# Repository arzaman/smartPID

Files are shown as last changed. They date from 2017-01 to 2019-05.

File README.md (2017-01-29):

# smartPID

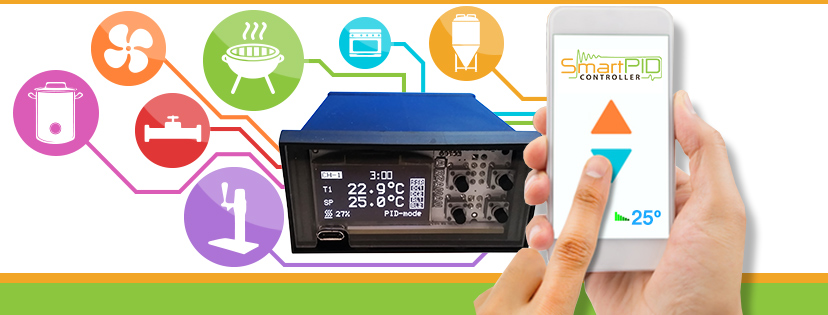
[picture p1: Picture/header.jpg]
smartpid header

Professionally engineered, SmartPID Controller is a high-tech product that facilitates temperature and process control: heating or cooling. 
Compared to your basic on/off thermostat, SmartPID is a piece of futuristic wonder.  

Compared to simple on/off thermostat SmartPID controller can collect temperature from multiple sensors, apply a custom and programmable control logic and drive different load (heater, cooler, valve, fan) with PID precision algorithm
You can easily replace your thermostat and add full process control to your application, data log and remote management

SmartPID Controller can control any thermo regulated process (heating or cooling) and any applications locally or remotely
It is flexible and very powerful device which can be programmed and adapted to any custom application

SmartPID Controller is 100 compatible with Arduino ecosystem

SmartPID Controller is a must device for Do-It- Yourself Enthusiasts, Software geeks, Makers, but also professionals that need affordable process controller

From homebrewing or wine making to aquarium or refolow oven temperature control SmartPID can add precision, power, flexibility programmability

In one word make your temperature process control SMART

All applications benefit from a full set of common features that are the baseline to developing smart applications.

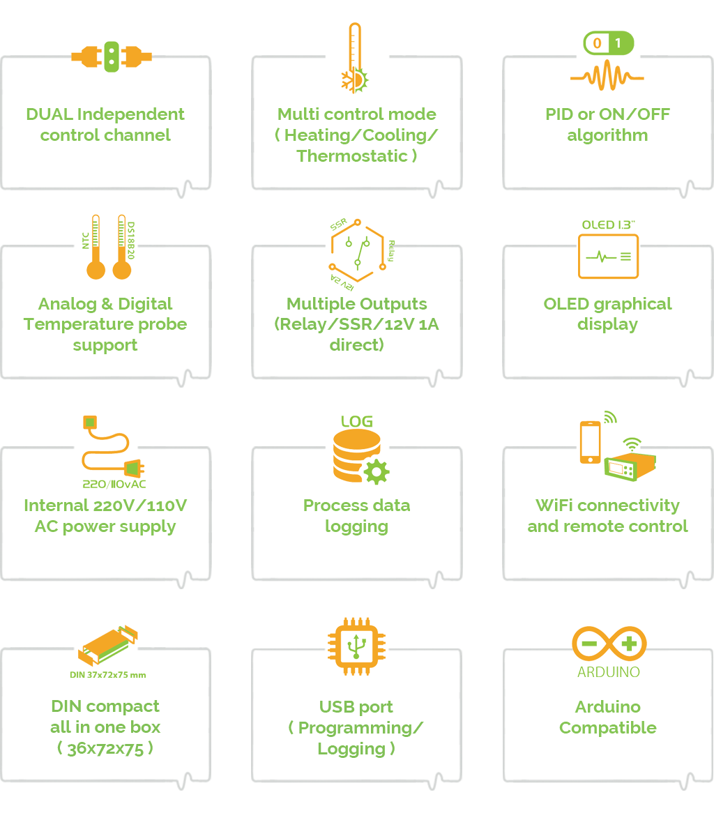
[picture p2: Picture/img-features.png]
smartpid feature


SmartPID is a masterpiece of engineering. We have done our best to incorporate a ton of advanced features into a single compact box. Below you will find a table with all technical characteristic

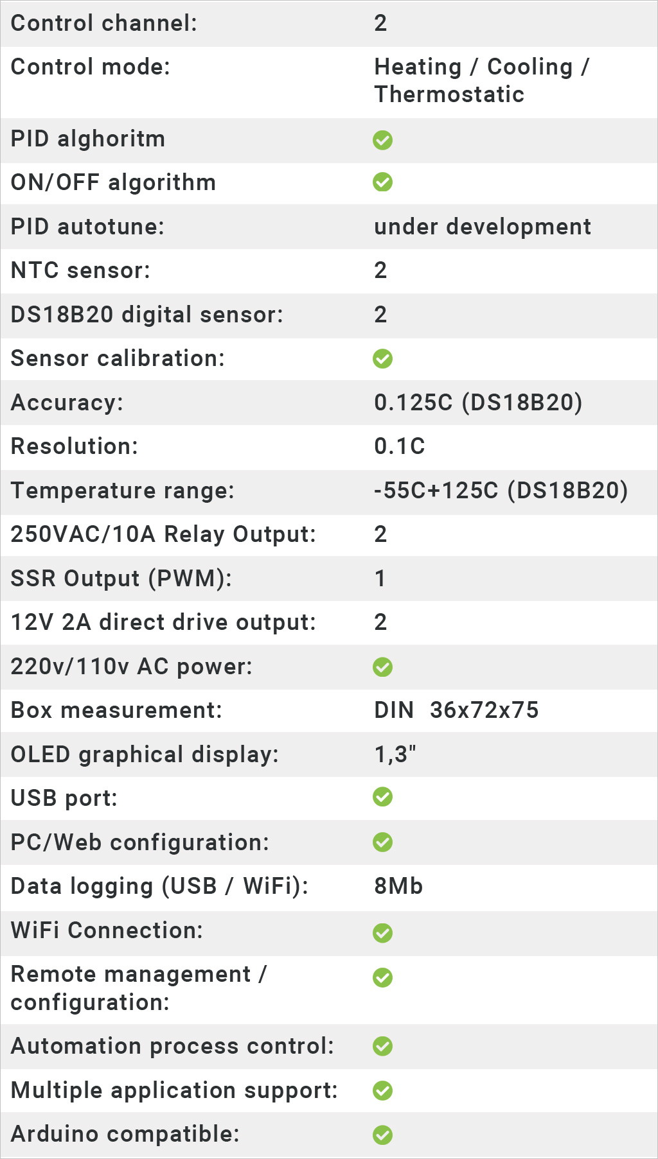
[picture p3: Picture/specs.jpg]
smartpid technical


SmartPID is powered by SAMD21 32-bit ARM® Cortex®-M0+ by Atmel

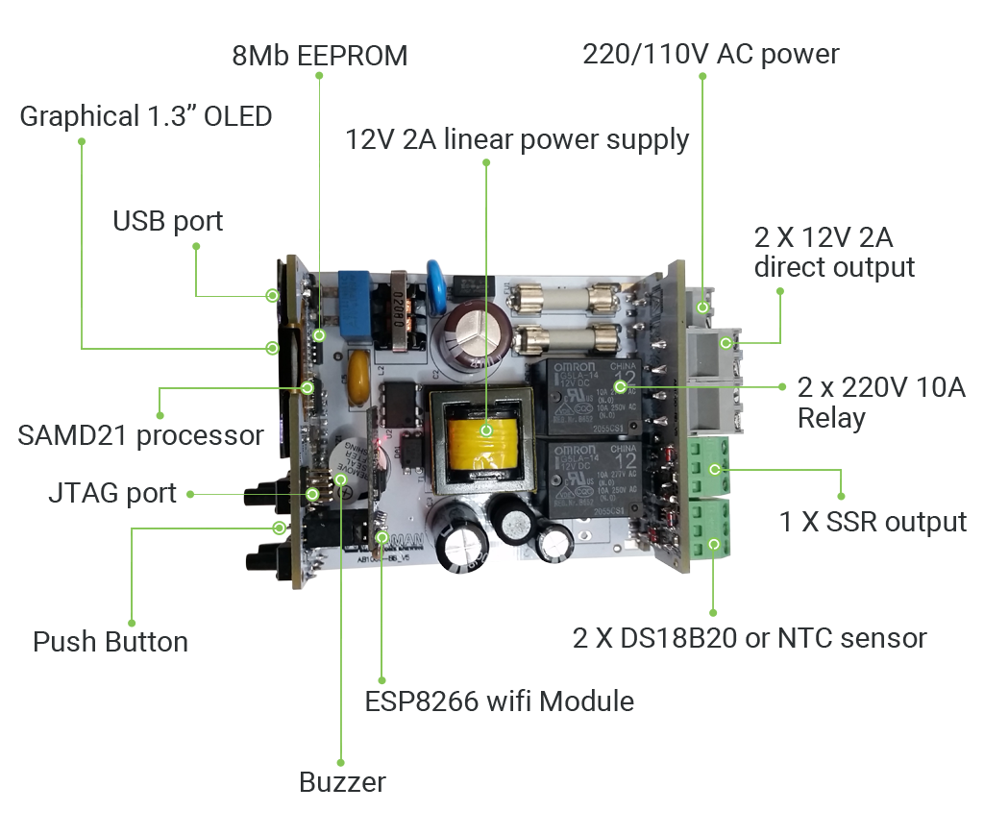
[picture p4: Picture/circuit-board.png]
smartpid circuit board


 SmartPID is 100% compatible with the Arduino echo system: you can plug in your PC via USB and program through the Arduino IDE.   

The key benefits of this design choice are

SAMD21 processor-based (like Zero or MKR1000)   
Dedicated USB bootloader and board definition   
Fully programmable via Arduino IDE   
Full set of support libraries available
smartPID has been designed by a maker for the maker community

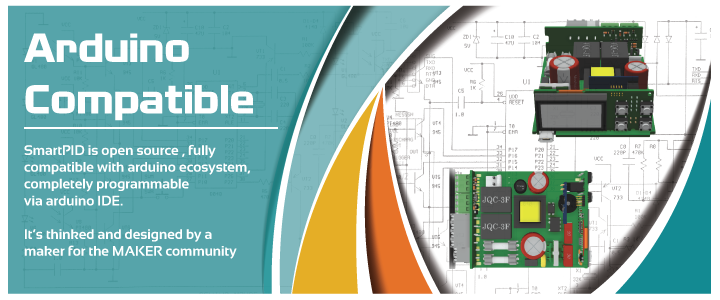
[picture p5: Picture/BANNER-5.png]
smartpid arduino


smartPID IS IoT ready 

One of the unique smart features of the SmartPID Controller is its capability to store process log data and then make that data available either locally via USB interface or remotely via the cloud. 

You can easily access your data from the web on a desktop, smartphone, or tablet, which is perfect in case of critical situations that involve alarms and triggers. 

Plus, if your fridge goes into a block stage or your food dehydrator finishes its process, you can set up SmartPID to let you know.

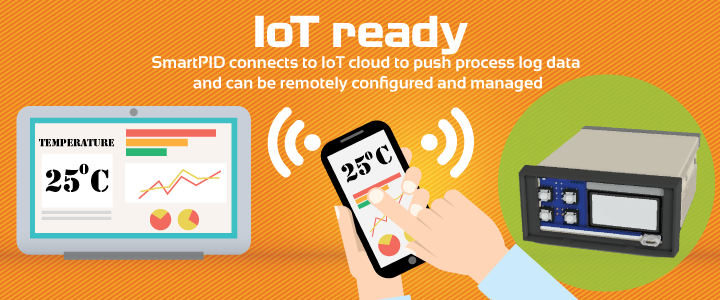
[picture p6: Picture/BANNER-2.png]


SmartPID is connected to thingspeak

Among many different possible IoT solutions for SmartPID in this phase is the Thingspeak service. 

Thingspeak is based on a number of useful features that make it easy to use and integrate the SmartPID project.

-Real-time data collection and storage of process data generated by SmartPID

-Simple and effective data visualization in both private and public channels

-MATLAB® for data analysis and manipulation

-Alerts and triggers for integration with other services

-Scheduling

-Open API

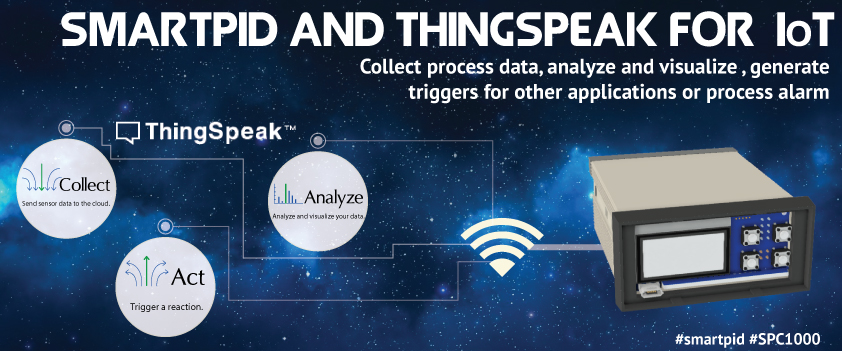
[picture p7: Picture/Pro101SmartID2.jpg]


The relevant code is available on github, and in the future, a dedicated cloud service will be provided

SmartPID dedicated APP

We have developed a mobile app prototype for Android in order to retrieve data from the cloud server and in turn visualize that data on a smartphone.  

SmartPID pushes log data to a remote server so that the mobile app can retrieve it in a secure and encrypted way.

The smart app allows you to do the following:  

-Login and authenticate user login on the server in order to access it in a secure way  

-Display and visualize data via a dashboard so that the user can select a specific controller and data (filtered by date/time) and display the data in a graphic or tabular way 
 
-Configure the device (this part is still under development)

-You can configure all the unit parameters (HW set up, process parameter) via a web interface or mobile app and upload your configuration options on the device. Configuration options can then be stored on the server and used at any time. 

You can also set a temperature threshold and get notifications by local alarm, email, or Twitter.

developing application for both android and IOS and set up all the server infrastructure is complex and requires lot of investment, this is one of the part in scope od the crowdfunding campaing

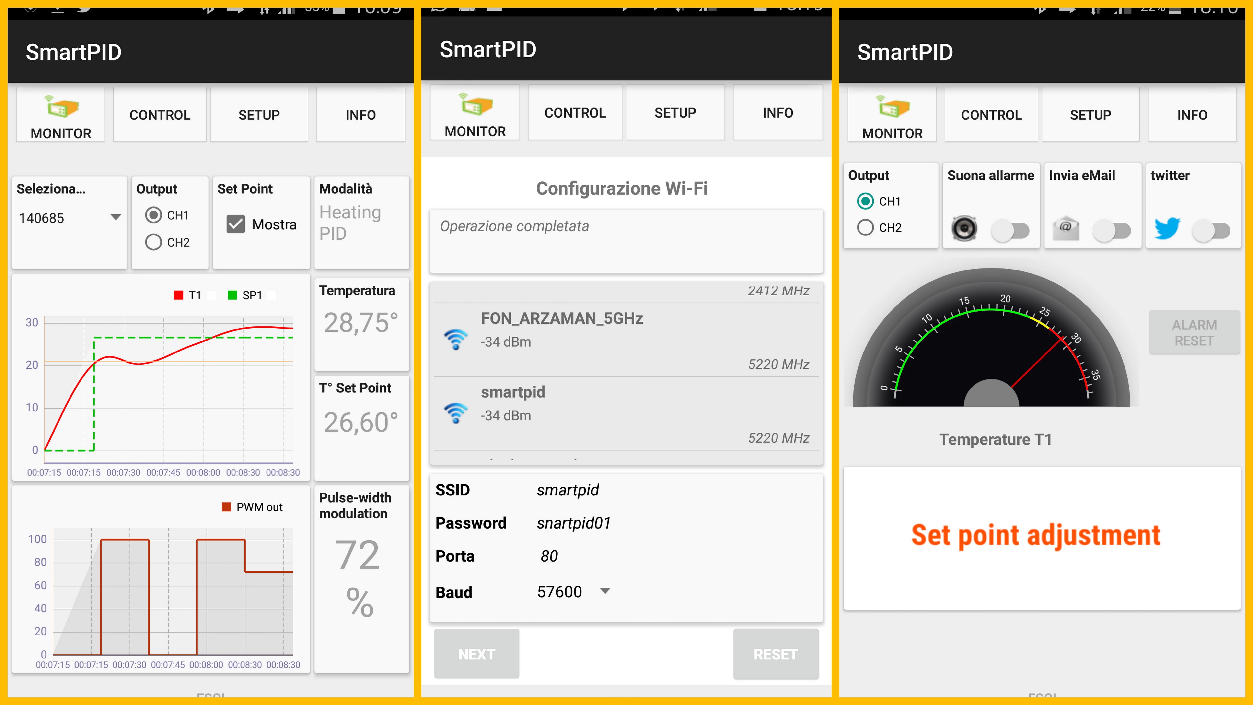
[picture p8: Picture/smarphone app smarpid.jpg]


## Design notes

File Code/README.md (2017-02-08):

# TEST APP code

this folder contains the source code for a test application that allow you to perform test of all HW components

the code is complied with arduino IDE 1.6.13 and SAMD core 32 BIT ARM Cortex M0+ version 1.6.11
notice that the binary code produced should be loaded with the smartPID MSD bootloader and is not compatible witn SAM-BA bootloader

it's needed to instal smarPID board definitio, please see "driver" section

Test area:

MCU test 

EEPROM (read e write)

OLED (graphic and text)

tactile switch

buzzer

wifi module (serial connection and FW version)

temperature read (NTC and DS18B20 on both port)

oututput activation (SSR/relay/12V DC)

USB port test

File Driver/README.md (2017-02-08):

# DRIVER

this folder contains 

Board Definition. the information package to install the board under the arduino IDE

open your Arduino preferences (File > Preferences). Then find the Additional Board Manager URLs text box, and paste the below link 

https://raw.githubusercontent.com/arzaman/smartPID/master/Driver/SPC1000/package_arzaman_index.json

Then hit “OK”, and travel back to the Board Manager menu. You should (but probably won’t) be able to find a new entry for SPC1000 board. If you don’t see it, close the board manager and open it again.

USB serial driver

After downloading, copy down the location of the arzaman.inf file

Open your Device Manager
In Windows 8 or 10, simply search for "Device Manager" and select the Windows app
In the Device Manager, expand the "Other devices" tree -- you should see an entry for "Unknown Device", Right-click and select Update Driver Software...

Select Browse my computer for driver software. On the next screen

Paste the directory location of your arzaman.inf files into the search location. Then hit "Next".

Click "Install" when the next pop-up questions if you want to install the driver. If you get any warning for unknown source of the driver please accept.

The driver installation may take a moment, when it's done you should be greeted with a "successfully updated your driver software" message!

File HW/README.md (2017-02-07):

# HW (schematic and pcb)

this folder contains the SmartPID electric schema and PCB

the controller is composed by 3 PCBs

Front Board
contains the SAMD21 processor, the EEPROM, the OLED display and push button. there are 2 sockets one for the ESP8266 module and the other one for SWD programming.

Base Board
it connects the 3 PCBs and contains all the linear switching 220AC/12VDC power supply. On the board there are also the 2 mechanical relays and the buzzer

Rear Board
provides the I/O lines via terminal blocks and contains all the power driver and protection electronic

CAD file are in altium designer format

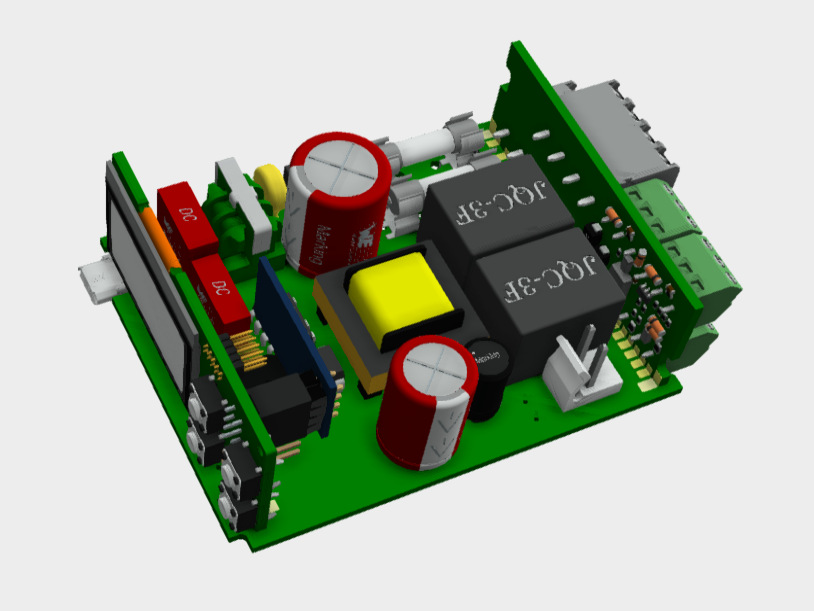
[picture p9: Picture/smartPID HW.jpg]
smartpid HW


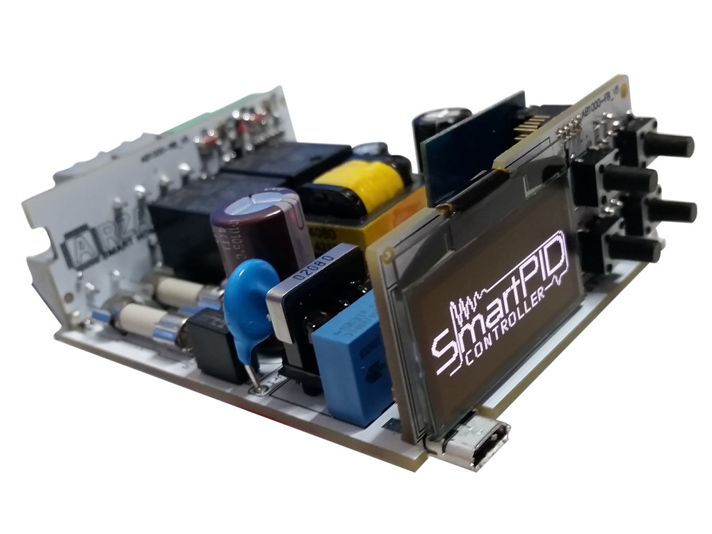
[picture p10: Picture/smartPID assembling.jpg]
smartpid assembling


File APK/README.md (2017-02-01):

# APK

this folder contains the the android application pakage 

download on your smartphone and please make sure that
Your android version is 5 or greater
You activate USB debug mode under development option menu
You accept during the installation APK from “unknown source”

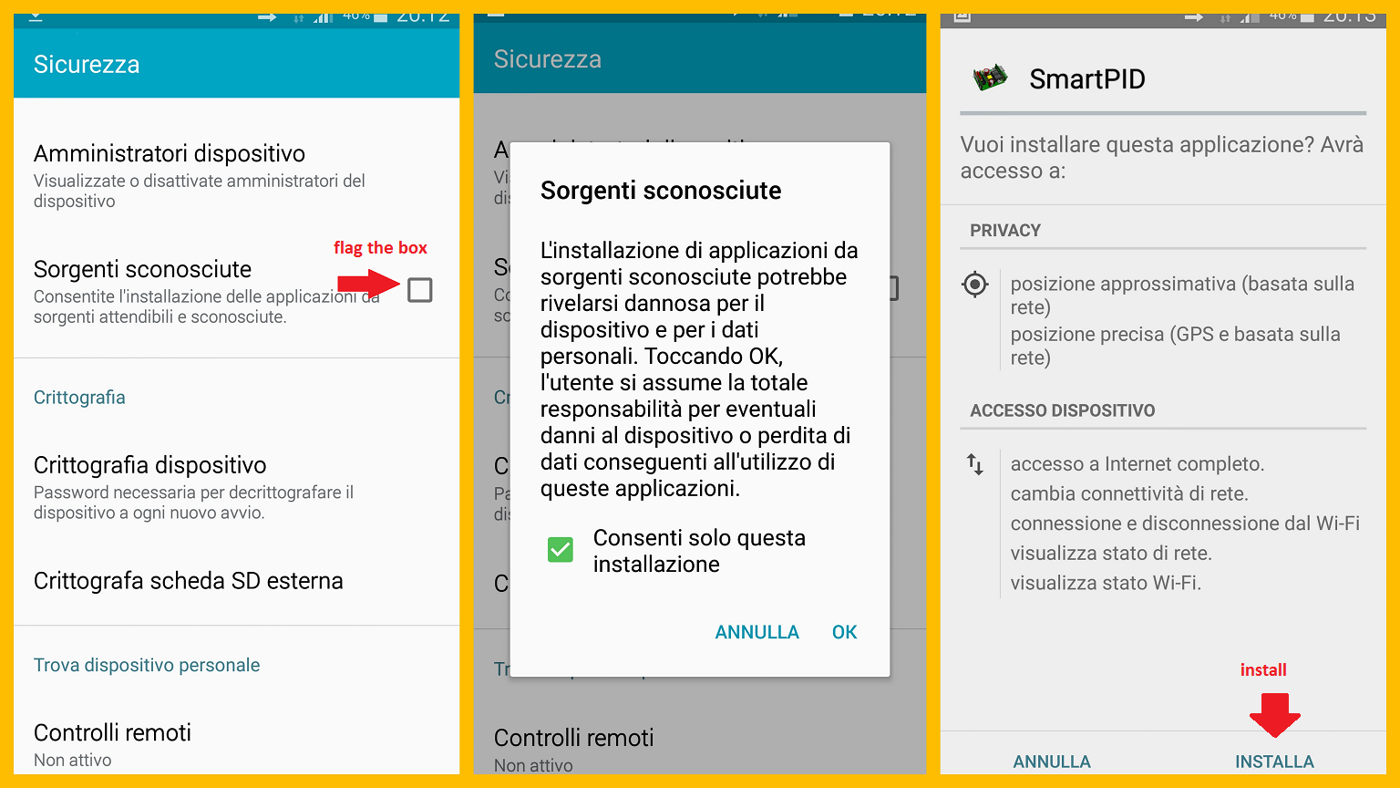
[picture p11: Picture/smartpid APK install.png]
APK install


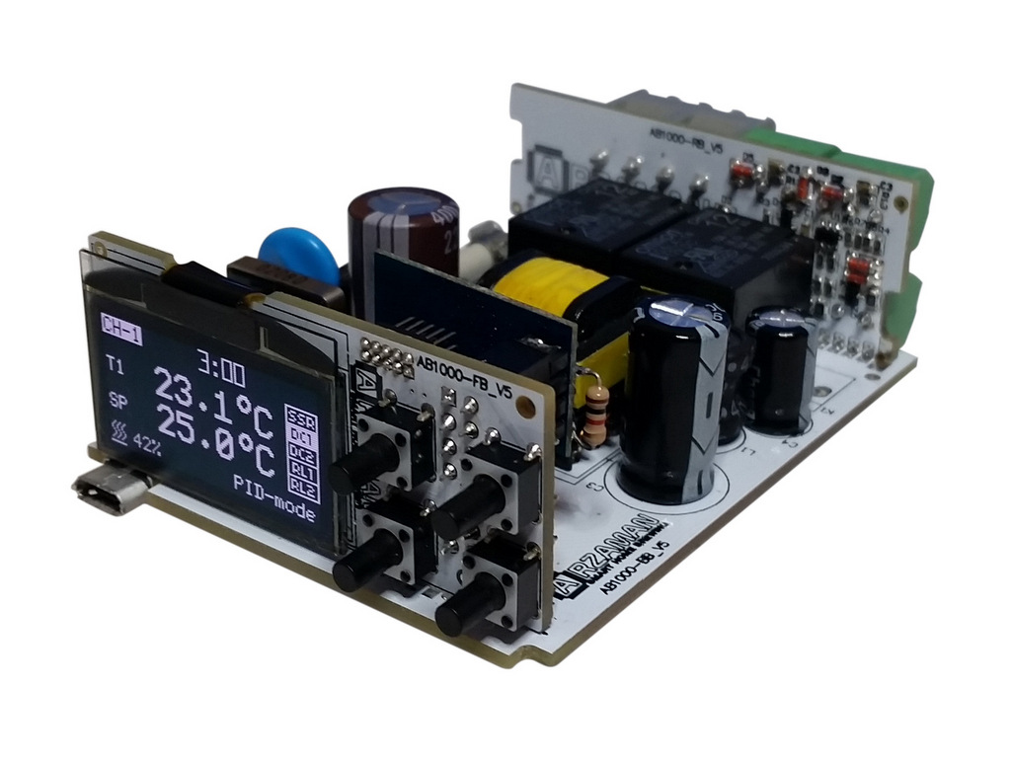
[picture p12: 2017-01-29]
Picture/smartPID HW overview (1).jpg

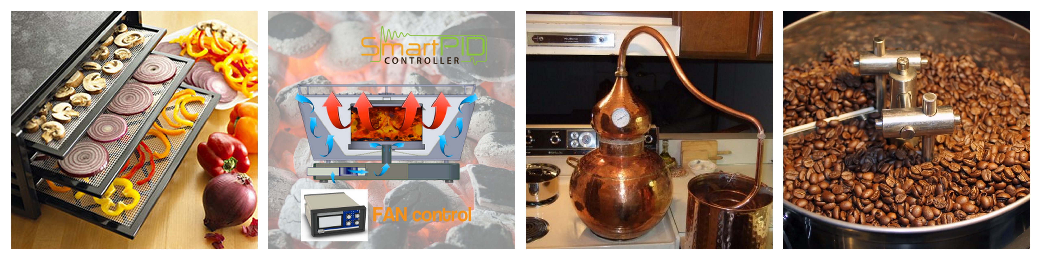
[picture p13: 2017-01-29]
Picture/multipe smartpid applications.jpg

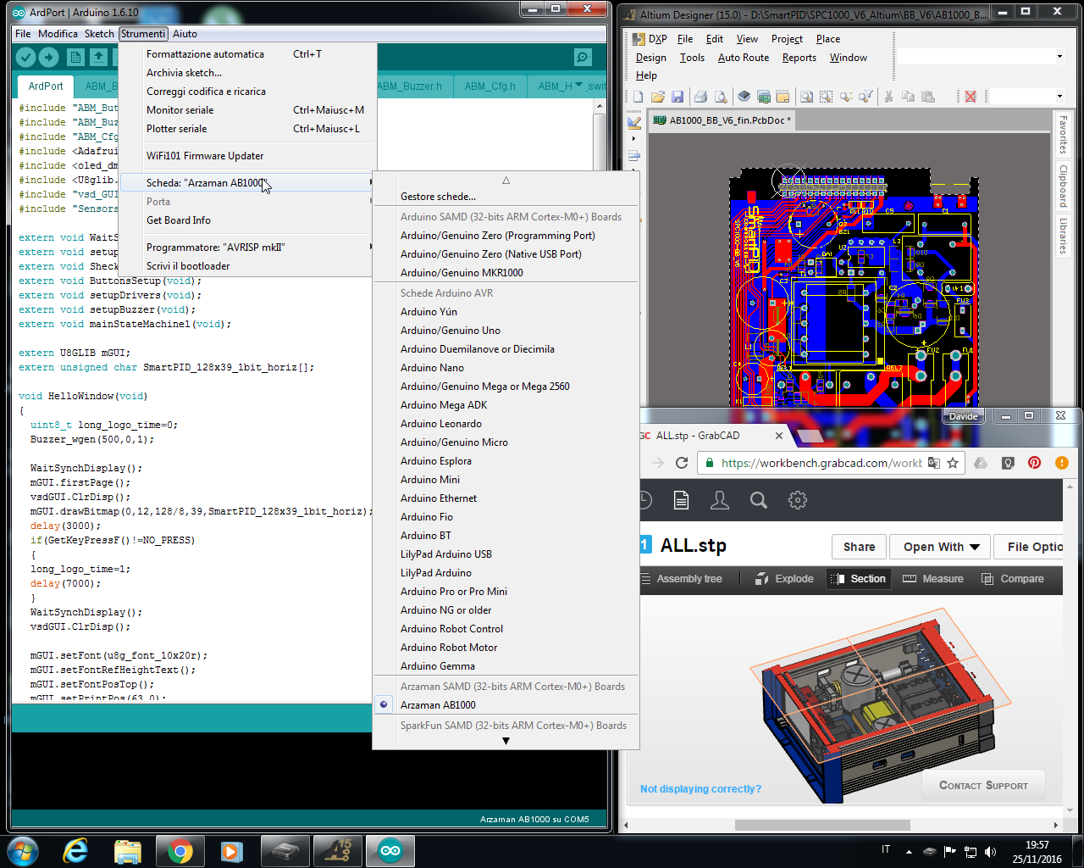
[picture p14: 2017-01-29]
Picture/2016-11-25 19_57_43-Greenshot (1).png

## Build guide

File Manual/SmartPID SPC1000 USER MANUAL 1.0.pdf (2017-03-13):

User Manual

# User manual

11-03-2017

Version 1.0

Company Information

Copyright and third-party information as required

## Document Revisions

Date

Version
Number

Document Changes

11/03/2017 | 1.0 | First draft

## Table of Contents

## Safety & Precaution

Ensure that the product is always used within the specifications

Do not use product close to flammable and explosive gas otherwise injury from explosion may occur

Never disassemble, modify, or touch any of the internal part to avoid electric shock or malfunctions

Do not use the relay over their life cycle and do not exceed the rated load of the outputs

Do not touch the terminals at least while power is being supplied. Doing so may occasionally result in injury due to electric shock.

enter the product.

Do not allow water or any liquid enter the product. Enclosure is not water prof

The board is sold as a DIY standalone component and people buying should take care of connecting and integrating with their own system. The manula connection diagram and short explanations but minimum expertise in electric circuit is needed.

The board is powered by High Voltage 220/110V so you must be very careful and all connections are at your own risk. If you are not familiar with electricity and power please ask a technician to help you. I'm not responsible for any damage or risk you can create

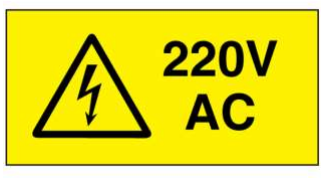
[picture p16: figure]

## 1 SmartPID SPC1000 overview

### 1.1 Scope and Purpose

The purpose of this document is to describe in detail the user application software called home brewing smart app. The document provide the support to configure the application SW and run all different use cases

For the HW installation and basic configuration (including wifi) please refer to proper manuals.

### 1.2 SmartPID overview

The smartPID controller has been designed to replace low cost simple thermoregulator with a smart controller that can be programmed and adapted to any process. In the specific case the brewing process has been fully automated.

Using the Same DIN enclosure SmartPID microcontroller could replace almost plug an play the standard thermostat in brewing application with providing following key feature

- process enhancement and full automation (step mash/profile/recipe management)
- flexible programming (mashing/fermenting , different set up)
- Higher accuracy (PID control)
- Wide variety of HW (Electric Heating/Gas Heating, Relay/SSR)
- Remote control via dedicated smartphone app or web

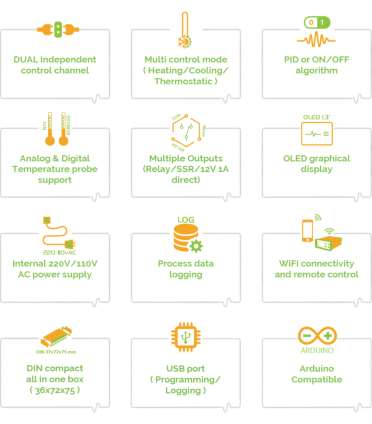
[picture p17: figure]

In term of technical characteristic SmartPID support

- Dual Independent channels
- PID control and ON/OFF control with hysteresis
- 2x Relays output
- 1 SSR Output
- 2 x 12V 2A power output
- 2 Digital temperature probe input OR NTC input (configurable)
- OLED graphic display
- On Board EEPROM for data logging and parameter configuration/recipe store
- Process data logging
- SW update and loading via USB
- WiFi connection to remote server
- Buzzer events indication
- 4 push button interaction
- 220V power supply
The SmartPID controller is complemented by the dedicated smartphone app that allow the user to remote control the brewing process
For details on how to pair the smartPID with the app and configure wifi and thingspeak service please refer to installation and integration manual

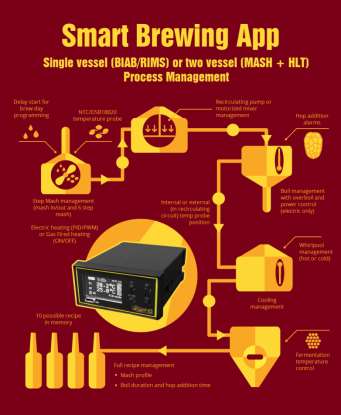
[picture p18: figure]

## 2 SmartPID Homebrewing application

Via HW set up configuration SmartPID can be adapted to manage different brewing setup, the HW configuration allows to assign different processes/logicalchannels to different physical HW resources. This provide great flexibility to manage different heting method (gas or electric) and different pump / stirrer (220AC or 12V DC)

Two main configuration support

a) BIAB/RIMS - PID or ON/OFF, single vessel system (one temperature + one heating element)
b) BIAB/RIMS process + HLT management , dual vessel dual PID (2 temp probe + 2 heating element)

Below some example to illustrate the flexibility and multiple configurations possible

BIAB/RIMS single PID (on/off) control - heating (gas or electric) + pump

SmartPID reads temperature from 1 probe and drive the heating element via SSR out to automate all steps with temperature control

Pump to recirculate wort or a motor stirred is controlled during all process automatically or manually

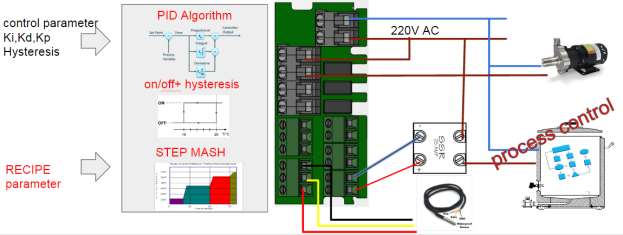
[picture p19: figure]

Possible heating output configurations

- SSR for electric heating [PID+PWM control algorithm]
- 220V AC relay for electric heating [ON/OFF algorithm]
- Direct solenoid valve drive for GAS heating [ON/OFF algorithm]

Automatic or manual (soft switch) pump drive with 2 possible configurations

- 220V AC relay pump drive
- 12V DC direct pump drive

BIAB/RIMS dual PID (on/off) control - heating (gas or electric) - pump

SmartPID reads temperature from 2 probe and drive 2 heating element interdependently the mash tun with full process automation and hot liquor tank for sparge water temperature control

Pump/Stirrer can be controlled automatically or manually as in single vessel process

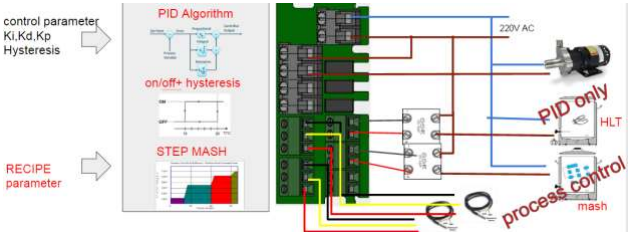
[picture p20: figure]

Possible heating output configurations

- 2 x SSR for electric heating [PID+PWM control algorithm]
- 2 x 220V AC relay OR direct solenoid valve drive for GAS heating [on/off]

Automatic or manual (soft switch) pump drive with 2 possible configurations

- 220V AC relay pump drive
- 12V DC direct pump drive

## 3 Smart HomeBrewing application SW

In this chapter the application SW installed and running on the controller is described in order to provide to end user the full understanding about how the brewing process automation has been implemented

### 3.1 Basic control principle

The core of this application is to implement a temperature control logic either to drive the heating element (electric or gas fired) in an heating process OR to drive a cooling system (typically a fridge) in a cooling process.

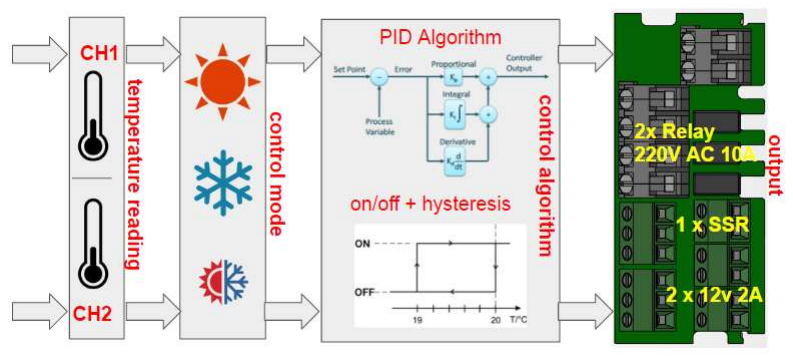
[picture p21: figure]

The main variable is the setpoint temperature selected by push buttons and this temperature is the input for the controlling algorithm that can be

1. PID algorithm + PWM control [Electric heating element]

Set point is compared with current temperature and the Proportional Integrative Derivative calculation are performed.

Ki,Kp,Kd must be configured or an auto tuning process is be started during set up phase (optional)

PID output drive a PWM power control block in charge to vary the duty cycle of PWM signals from 0 to 100%. The PWM output will drive the load via SSR. In this way a fine control of electric heating element can be performed

Two other relevant parameter can be configure and impact PID behavior

n) Window Size --> Period of the PWM signal
o) Sample Time --> PID sample time

2. ON/OFF algorithm [Gas heating and fridge cooling]

In this case set point is compared with current temperature and depending if the value is over or under the target the output is put in ON or OFF state driving either the mechanical relay or SSR

In order to avoid oscillations near the set point an hysteresis / dead zone should be implemented. The range of hysteresis should be configurable.

The ON/OFF control will be applied directly to heating systems gas fired via a gas ball valve

### 3.2 Brewing application principle

The brewing application implement a complete workflow in order to allow a fully automatic (or semi-automatic) brew day

The process is typically “linear” in time with execution of step by step sub process conditioned by some user defined parameter that represent the “recipe”

The process can be decomposed in following sub-process to execute sequentially

### 1. Recipe LOAD / set up

Before starting the process a recipe must be loaded and/or configured. The user is first requested if he wants to define a new recipe or to load a recipe either form EEPROM local repository or for external USB.
In case of new recipe the proper “recipe management” sw is recalled.
Once the recipe is finally selected the user is requested if he wants to start the process immediately or to activate a “delayed start”.
In the second case a proper delay can be configured (up to 12h) with up/down buttons in step of minutes. After the delay expiration the mash in process start normally.

### 2. MASH IN

During this mandatory step the water is heated in order to reach the mash in temperature (recipe parameter) while the recirculating pump, depending on proper set up parameter, is activated in order to have uniform heating of water.
Before starting the process the user is requested mandatory to confirm the water addition in order not to start dry heating. Immediately after a pump prime process is executed with 3 ON->OFF→ON short pump cycle in order to eliminate from the circuit air bubble.
During the process run the recipe pre-defined set point (Mash IN temp) can be changed anytime with Up/Down buttons.

Heating control is performed according to Unit and HW set up parameter (PID or ON/OFF algorithm). When the Mash IN temperature is reached a beep is played via buzzer, pump is stopped and system enter in “standby” waiting for the confirmation of the next step
NB during the standby time the temperature is maintained constant controlling the heating element

### 3. STEP MASH

This is the core of the process, the water is mixed with crushed grains and is heated in a step process with defined temperature and duration described in the recipe in order to allow starch conversion into sugar

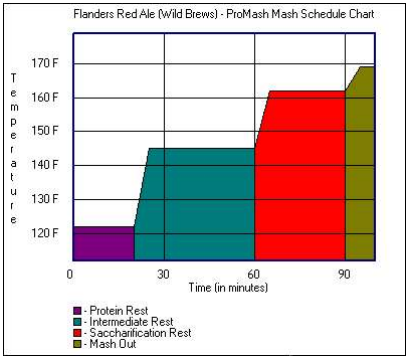
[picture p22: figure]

From controller point of view the heating element is managed according the algorithm selected (PID or ON/OFF) in order to reach the proper temperature, keep it stable for the step duration and then move to the next step.
Before entering the step mash the user should confirm that the malt has been added to the water .
According to pump configuration parameter a pump ON/OFF cycle run in background independently from temperature and step mash.
Manually override of recipe temperature set point can be done anytime with Up/Down button At the start (target temperature reached) and end (time expired) of each step a beep is played via buzzer.
Once last step is completed the system enter “standby” mode waiting for confirmation of mash out and keeping the last temperature constant.
A-Amilasi2 step is mandatory , the other step can be skipped putting duration=0 in the recipe

The program performs some integrity check and try to avoid user mistakes in configuration: if some input value are not coherent (ie a step with lower SetPoint than the previous one) the step is automatically skipped.

### 4. MASH OUT

In this mandatory step temperature is raised as soon as possible to the mash out temperature defined in the recipe. This temperature is kept for the duration inserted in the recipe.
Before entering this step the user is requested to confirm iodine test execution that provide evidence of the starch conversion.
During this step PUMP is managed according to parameter configuration either OFF or with ON/OFF cycle like in step mash
Once the mash out time is expired a beep is played via buzzer and then the system enter in “standby” waiting confirmation for boiling phase. Temperature should be kept constant all the time.

### 5. BOIL AND HOP ADDITION

After mash out the wort is heated until full boil and then the boiling phase start for a period defined in the recipe. During the boil phase multiple hop additions are executed.
Before entering in the boil mode the user is requested to confirm the malt removal/filtering execution.
Since there is no need of fine temperature control, after mash out the heating element is fully powered until reaching the boiling point temperature (defined in the recipe). When temperature is reached a beep is played and timer for boil duration started
The heating element in this phase is manually and statically controlled (no temperature control) using PWM algorithm that allow to throttle power from 0% to 100%.
Pump is controlled according the set up configuration either fully OFF or ON upon certain temperature (safe limit temp for the pump)

The hop addition process runs in parallel and provide a sound beep/display advice every time hop should be added . The number of hops to be added and time are part of the recipe parameter. The time parameter is used as a countdown and the value provide exactly reaming boiling time

After boil time expiration heating element is switched off, as well pump and system enter in cooling mode

### 6. COOLING/WHIRPOOL

after boil time completion heating element is switched off and beer is cooled up to temperature defined in process parameter and temperature is reported on the display. In this phase pump is switched on or off according to whirlpool parameter in process parameter configuration
It’s possible to perform hot or cold whirpool

## 4 Menu navigation

In following chapter the complete menu structure and navigation is reported, navigation trough menu and selection is performed via tactile switch on the front panel

Each button get its own functions and meaning in the proper context

a) UP/DOWN
a. Scroll in configuration menu
b. Increase decrease temperature value
c. Scroll in value in configuration menu
a) ENTER
d. Select/enter a specific menu
e. Select/confirm a specific value
f. Confirm action upon prompt request
b) Start/Stop
g. Start process
h. Stop Process

### 4.1 Main Menu

After the boot smartPID enter in a standby mode with all outputs off and the user can select the main menu items

The top level menu corresponds to the main SmartPID functions

1. Status Mode --> it’s a simple status where the temperature of the two channels is reported and user can activate / deactivate manually all the outputs (soft switch function)
2. Configuration Menu--> under this menu all the specific smartPID and process parameter configuration is performed
3. Connectivity and Log--> in this menu the user can configure all the wifi parameters, see the connection status, configure the remote server for the data logging. This functions are performed in cooperation with the smartphone app [See installation and configuration manual for details]

4. Recipe Management --> this menu allow the user to enter/edit/view the recipe for the brewing process either the step mash profile or the boil/hop addition schedule.
5. Run Mode--> trough this menu user start the process either in manual or fully automated mode

### 4.2 Status Mode

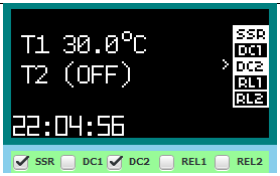
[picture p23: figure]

In the status mode the temperature of the T1 and T2 ports is reported as well as the time from the boot of the application. If no temperature probe is connected an error is reported

Moving with UP/DOWN button user can select any output and pressing SET the output can be activated and deactivated. On the OLED the relative label changes the color

To exit the status mode long press S/S button

### 4.3 Configuration

This menu is dedicated to all the configuration operations that typically are done once during the initialization / setup

1. HW setup --> the HW resources are configured and assigned to I/O process
2. Unit Parameter--> the main parameter that control the PID process behavior are configured in this menu
3. Process parameter--> homebrewing process specific parameter are configured in this menu
4. PID auto tune--> this is a special section to configure and run the auto tune process to help end user to calculate critical parameters Kp,Ki,Kd that regulate PID behavior

### 4.3.1 HW setup

This section allow to configure physical resources and assign properly to process/channels

Heating Mode User can select the control mode for the heating element -Electric (PID algorithm) -Gas (ON/OFF algorithm)

Control Mode User can select the proper set up of his brewing system deciding to use one or two control channels -Single Vessel - Mash Only -Dual Vessels – Mash + HLT

Mash Heating Through this menu is possible to assign to the mash channel/process the specific output among all possible

HLT Heating Through this menu is possible to assign to the HLT channel/process the specific output among all possible Notice that this is possible if control mode has been selected MASH+HLT

PUMP (stirrer) Finally the pump output should be assigned to a physical resources Note that in order to avoid conflict the resources already assigned can’t be selected

Button Beep Pressing the front panel button generate a short “beep” , through this option is possible to silent the smaprtPID Process sound advice are generated anyway

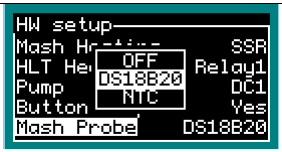
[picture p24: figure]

Mash Probe The proper temperature sensor is selected and assigned to mash process/ channel -digital one wire sensor DS18B20 -NTC sensors 10K

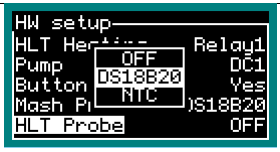
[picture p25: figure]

HLT Probe The proper temperature sensor is selected and assigned to HLT process/ channel Sensor type can be different from mash one since two channels are independent

### 4.3.2 Unit Parameter

This section allow the user to configure global parameter that regulates the overall SmartpPID behavior

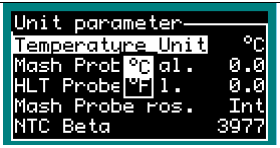
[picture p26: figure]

Temperature unit This menu allow the user to select the proper measurement unit -Celsisus -Fahrenheit Same configuration should be reported on the smartphone app

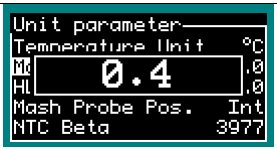
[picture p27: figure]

Mash Probe Calibration It’s possible to add an offset of +- 5c to the mash temperature probe reading to compensate any measurement error

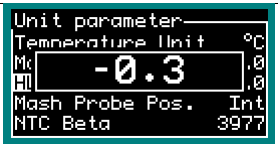
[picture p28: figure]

HLT calibration It’s possible to add an offset of +- 5c to the HLT temperature probe reading to compensate any measurement error

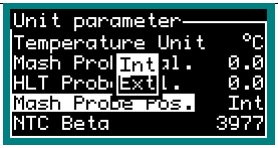
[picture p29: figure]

Mash Probe position This is an important parameter that defines where is located the mash temperature probe -internally to the mash tun -externally in the recirculating circuit See appendix for pump cycle descriptio

NTC beta User can select the Beta coefficient for NTC sensor , most common value are reported Beta will affect the temperature reading and so the precision, try to find the proper one according to spec of your NTC

### 4.3.3 Process parameter

This section allow the user to configure all the parameter that are specific for the home brewing process, each of them influence the workflow and overall process execution

Below table reports for each parameter a short description and the range of valid value

Parameter Type | Parameter | Description | Range | default
| Boiling Point | Define the temperature considered as start of the boiling process | 95c-105c | 100c
| PWM% @ Boilnig | Define the PWM output % to apply when the temperature reach the boiling point | 70%-100% | 100%
| PUMP cycle | Define the duration time in minute for the pump ON | 5m-20m | 10m
| PUMP rest | Define the duration time in minute of the pump OFF | 1m-5m | 2m
| Pump stage | Define in what stage pump should be used. For each stage Y/N flag should be configured | Mash In Y/N Step Mash Y/N Mash Out Y/N Boil Y/N | Yes all stages
| User Prompt | Define in what stage transition the system enter stand by and ask for explicit confirmation to continue Y → ask confirmation N→ proceed without | Malt Addition Y/N Iodine test Y/N Malt Extraction Y/N | Yes all stages

BIAB
parameter

| confirmation
Whirlpool | Define whether to apply or not the whir pool and in case if it’s hot or cold whirlpool | OFF Cold Hot | OFF
Whirlpool duration | Define the whirlpool duration in minutes | 0m-30m | 5m
Cooling Temperature | Define temperature where the cooling process end. | 10c-30c | 25c
Kp/Ki/Kd For MASH and HLT | Define the proper constant value for the PID algorithm | Kp x—y Ki x—y Kd x—y
SAMPLE time | Define the sample time of temperature in ms | 1000ms 4000ms | 1500ms
PWM Frequency | Define the PWM period/window size for PWM control in ms | 500ms 7000ms | 3500ms
Hysteresis For MASH and HLT | Define the hysteresis in ON/OFF control in C/F | 0c 5c | 2c
Default SP For MASH and HLT | Default temperature set point | 0-100C | 50c

Process
Parameter

### 4.3.4 PID auto tuning

This is a special advanced menu that allow to start a specific SW algorithm that try to estimate the best value of KpKiKd constant considering the specific setup

In this section is not reported the complete theory behind this algorithm but just how to configure and start . There are few resources on the internet that explain the Ziegler-Nichols method implemented, as resource starting point refers to Wikipedia page

https://en.wikipedia.org/wiki/PID_controller

PID auto tune RUN Whene the autotune is in run mode the PID try first to reach the set point using the default parameters

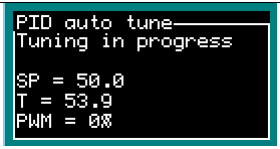
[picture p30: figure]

PID auto tune progress Once the set point is reached the auto tune starts some step cycle with OutputStep increase and decrease calcualting the time to reach SP+-NoiseBand temperature value and evalaute system reaction

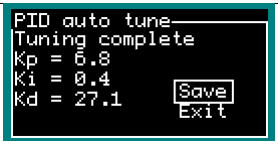
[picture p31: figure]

PID auto tune complete If the alghoritm converge (it can take also one hour) the Kp,Ki,Kd calcualted are reported and user can save as default value Notice that the auto tuning process is per channel

### 4.4 Recipe Management

The brewing process automation is based on a concept of “recipe” that defines the input parameter to the controller

Through this section is possible

VIEW→ load recipe from local EEPROM selecting index number and allow to display the full set of parameter in each sub-menu

EDIT /DELETE→ load recipe from local EEPROM selecting index number and allow to change/modify/delete all parameter in each sub menu. At the end of the modification user can save on the same index (replace) or with a new index (clone).

NEW → allow user to define a new recipe from scratch and add all parameters divided in two submenu. For parameter list see the doc spec chatper 3.3.3

At the end of the recipe definition the entire recipe can be saved in the EEPROM with a proper index

When a new recipe is inserted two main section should be edited

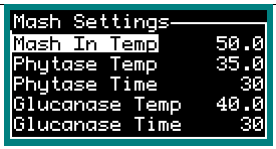
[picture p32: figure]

Mashing

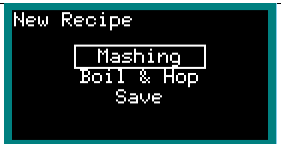
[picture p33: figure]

For each step of the mash program a couple of temperature/time value should be entered

If the time is set to 0 the step is skipped

See below table for more details

Boil & Hop Settings The toal boil duration should be specified as well the number of hop additions

Hop Addition Time For each hop additions defined in previous menu the total boiling duration is configured

Following table reports the step mash structure of a generic recipe. Each recipe is made by the complete set of parameter.

In red the mandatory parameter

Parameter Type | Parameter | Description | Range | default
| temperature | Define the temperature for mash IN step | 20c-78c | 50c
| Fitasi Temp/Duration | Define the temperature and step duration in minute | 25c-55c | 35c
| Glucanasi Temp/Duration | Define the temperature and step duration in minute | 35c-50c | 40c
| Protesi Temp/Duration | Define the temperature and step duration in minute | 45c-60c | 50c
| B-Amilasi Temp/Duration | Define the temperature and step duration in minute | 50c-70c | 63c
Mashing | Mash IN

| A-Amilasi1 Temp/Duration | Define the temperature and step duration in minute | 60c-76c | 67c
| A-Amilasi2 Temp/Duration | Define the temperature and step duration in minute | 60c-76c | 73c
| Mash Out Temp | Define the temperature for mash out step | 70c-80c | 77c
Boiling&Hop addition | Boil Duration | Define the duration of the boil phase in minute | 30m-180m | 90m
| #Hop Additions | Define how may hop addition are needed | 0-10 | 1
| Hop(x) time | Define the time in minute when hop #x should be added | 0m-Boli duration | Boil duration

Some consistency check are performed during the input of the parameter

- Temperature consistency check→ each step should have a starting point temperature > temperature end point of the previous step. Example: if the proteasi is set to 55c the next step like B-amilasi can start over 55c so the range will be 55c-70c.
The only exceptions is mashIN step that can exceed 4c the next step temperature
- Time consistency check → in boil addition the total boil time should be dived in slot according to number of hop additions. Each hop time should be < previous time. Example: boil duration 120min , 3 hops, 1st hop 60min → 2nd should be < 60min

### 4.5 Run mode

Entering the run mode allow the user to start the brewing process

Two possible run mode are possible

MANUAL MODE--> no step mash and automation is implemented, the temperature is controlled to reach the set point while the pump can be manually activated by long press of SET button

AUTO MODE --> a recipe is loaded and executed step by step

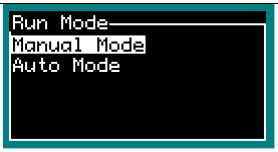
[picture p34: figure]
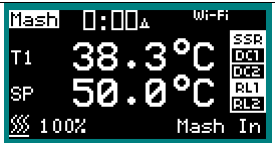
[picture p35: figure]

Manual Mode The system enter the run mode and starts controlling the heating elements / pump See process execution chapter for details of the information reported on the display

Auto Mode Before entering the auto mode user is requested to load a recipe from the memory or define a new one

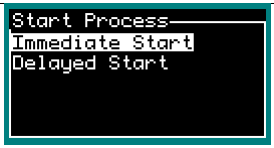
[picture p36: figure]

Delay Start Next step allow the user to define a delay start for the process or to start immediately

Delay start setting Entering the delay start menu a timer should be configured with UP/DOWN buttons

Water Added prompt Before starting the process a final check is performed to make sure that water has been added in order to avoid to damage the heating element.

## 5 Process Execution

Once the controller has started the run mode auto all the steps described in 3.2 are executed sequentially. Depending on the parameter configured in the process parameter section the user is prompted at each step or the process can be executed without any intervention

The main screen in run mode report following information

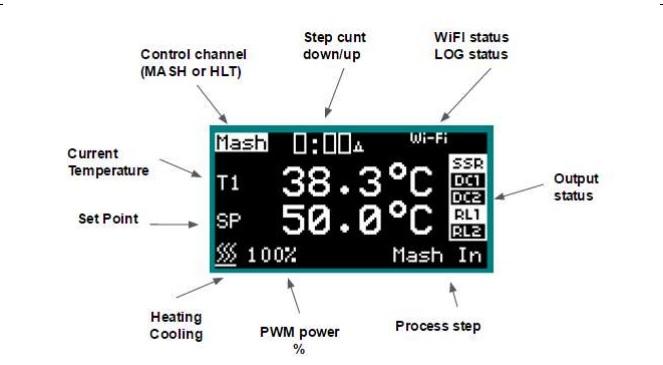
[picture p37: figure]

via the push button is possible to

- Switch to the graphic mode --> press SET
- Switch between count UP and count DOWN --> press S/S
- Modify the set point temperature --> UP/DOWN buttons
- Exit the process --> long press S/S button

The graphic mode reports the real time temperature and the set point, graph is automatically updated and scalded

Pressing SET button it’s possible to move to the HLT screen (if MASH+HLT has been configured) , the info provided are quite similar to the mash apart form the fact that the count up and down is not present and process step is substituted by control mode

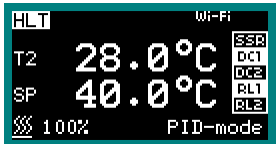
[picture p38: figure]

In manual mode the OLED report same info , it’s possible to activate and deactivate manually the PUMP/ stirrer by long press the SET button, pump status is reported in the bottom right corner

## 6 Appendix

### 6.1 Pump Cycle management

Following table reports the PUMP status in the different step of the process considering the temperature sensor position.

sensor position
Process
Stage | INTERNAL | EXTERNAL
recipe load | pump off | pump off
delay start | pump off | pump off
pump prime | Execute always pump prime immediately after start | Execute always pump prime immediately after start
mash IN | Pump stage mash IN = Y activate pump continusly (no pump cycle) Pump stage mash IN = N Pump OFF | PUMP always on until reach the the mash IN temperature
malt addition | pump is OFF for the whole duration of malt addition | pump is OFF for the whole duration of malt addition
step mash | Pump stage step mash = Y activate pump and execute pump cycle / pump rest Pump stage step mash = N Pump OFF | Execute always pump cycle and pump rest during pump rest the mash heating element is off (PID not invoked)
iodine test | pump is OFF for the whole duration of iodine test | pump is OFF for the whole duration of iodine test
mash OUT | Pump stage mash out = Y activate pump and execute pump cycle / pump rest Pump stage mash = N Pump OFF | PUMP always on until reach the mash OUT temperature
malt extraction | pum is OFF for the whole duration of malt extraction | pump is OFF for the whole duration of malt extraction

boil | Pump stage Boil = Y activate pump continuously up to PUMP STOP temperature Pump stage boil = N Pump OFF | PUMP always on untill reach of the boil temperature (PUMP stop temp ignored)
cooling | PUMP can be activated or deactivated manually soft switch like in manual mode | PUMP always on until reach of the cooling temperature
whirpool | PUMP is activated for the duration of the whirlpool (parameter whirlpool duration) It should be possible to stop the pump (stop the whirlpool) and reset the count down | PUMP is activated for the duration of the whirlpool (parameter whirlpool duration) It should be possible to stop the pump (stop the whirlpool) and reset the count down

### 6.2 Zeigler-Nichols PID tune

Another heuristic tuning method is formally known as the Ziegler–Nichols method, (https://en.wikipedia.org/wiki/Ziegler%E2%80%93Nichols_method) introduced by John G. Ziegler (https://en.wikipedia.org/wiki/John_G._Ziegler) and Nathaniel B. Nichols (https://en.wikipedia.org/wiki/Nathaniel_B._Nichols) in the 1940s. As in the method above, the Ki and Kd gains are first set to zero. The proportional gain is increased until it reaches the ultimate Ku, a which the output of the loop starts to oscillate. Tu and the oscillation period are used to set the gains as shown:

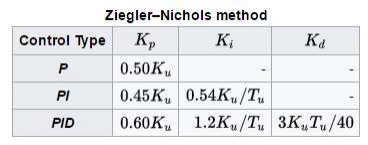
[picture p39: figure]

These gains apply to the ideal, parallel form of the PID controller. When applied to the standard PI form, the integral and derivative time parameters Ti and Td are only dependent on the oscillation period Tu

### 6.3 Data Logging structure

The main process parameter are logged either on the EEPROM or pushed to the external server via wifi (currently using the thingspeak service)

The information stored are the following for each channel

a) time stamp (format Epoch, ISO 8601, MySQL)
b) channel number (CH1 or CH2)
c) control mode (heating or cooling)
d) heating or cooling mode (PID or ON-OFF)
e) set point temperature
f) current temperature
g) PWM percentage
h) PID direction (cooling/heating or ON/OFF)

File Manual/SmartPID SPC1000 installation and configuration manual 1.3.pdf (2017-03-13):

### User Manual

# Installation and configuration manual

11-03-2017

Version 1.3

Company Information

Copyright and third-party information as required

## Document Revisions

Date

Version
Number

Document Changes

29/01/2017 | 1.0 | Initial Draft
1/02/2017 | 1.1 | Added safety and precautions
08/02/2017 | 1.2 | Added arduino guide, usb driver, fw upgrade, reset to factory
11/03/2017 | 1.3 | Review and corrections

## Table of Contents

## Safety & Precaution

Ensure that the product is always used within the specifications

Do not use product close to flammable and explosive gas otherwise injury from explosion may occur

Never disassemble, modify, or touch any of the internal part to avoid electric shock or malfunctions

Do not use the relay over their life cycle and do not exceed the rated load of the outputs

Do not touch the terminals at least while power is being supplied. Doing so may occasionally result in injury due to electric shock.

enter the product.

Do not allow water or any liquid enter the product. Enclosure is not water prof

The board is sold as a DIY standalone component and people buying should take care of connecting and integrating with their own system. The manula connection diagram and short explanations but minimum expertise in electric circuit is needed.

The board is powered by High Voltage 220/110V so you must be very careful and all connections are at your own risk. If you are not familiar with electricity and power please ask a technician to help you. I'm not responsible for any damage or risk you can create


## 1 SmartPID SPC1000 overview

### 1.1 Scope and Purpose

The purpose of this document is to describe in detail the installation and configuration process of the SPC1000 smartPID controller. For the user application feature and functions please refer to proper manuals.

### 1.2 SmartPID technical characteristics

The below table summarize the technical characteristic of SmartPID

FEATURE | SmartPID SPC1000
Control channel | 2
Control mode | Heating/Cooling/Thermostatic
PID alghoritm | Y
ON/OFF algorithm | Y
PID autotune | Y
NTC sensor | 2
Beta coefficient configuration (NTC) DS18B20 digital sensor | Y
| 2
Sensor calibration | Y
Accuracy | 0.125C (DS18B20)
Resolution | 0.1C
Temperature range | -55C+125C (DS18B20)
250VAC/10A Relay Output | 2
SSR Output (PWM) | 1
12V 2A direct drive output | 2
220v/110v AC power | Y
Box measurement | DIN 36x72x75
OLED graphical display | 1,3"

USB port | Y
I2C Expansion port | Grove I2C port (3v3)
PC/Web configuration | Y
Data logging (USB / WiFi) | 8Mb
WiFi Connection | Y
Remote management/configuration | Y
Automation process control | Y
Multiple application support | Y
Arduino compatible | Y

WIFI Module characteristics

IEEE 802.11 b/g/n Wi-Fi

WEP or WPA/WPA2 authentication, or open networks 802.11 b/g/n

Wi-Fi Direct (P2P), soft-AP

Integrated TCP/IP protocol stack

Integrated TR switch, balun, LNA, power amplifier and matching network

+19.5dBm output power in 802.11b mode

Power down leakage current of <10uA

Standby power consumption of < 1.0mW (DTIM3)

Mechanical Drawings

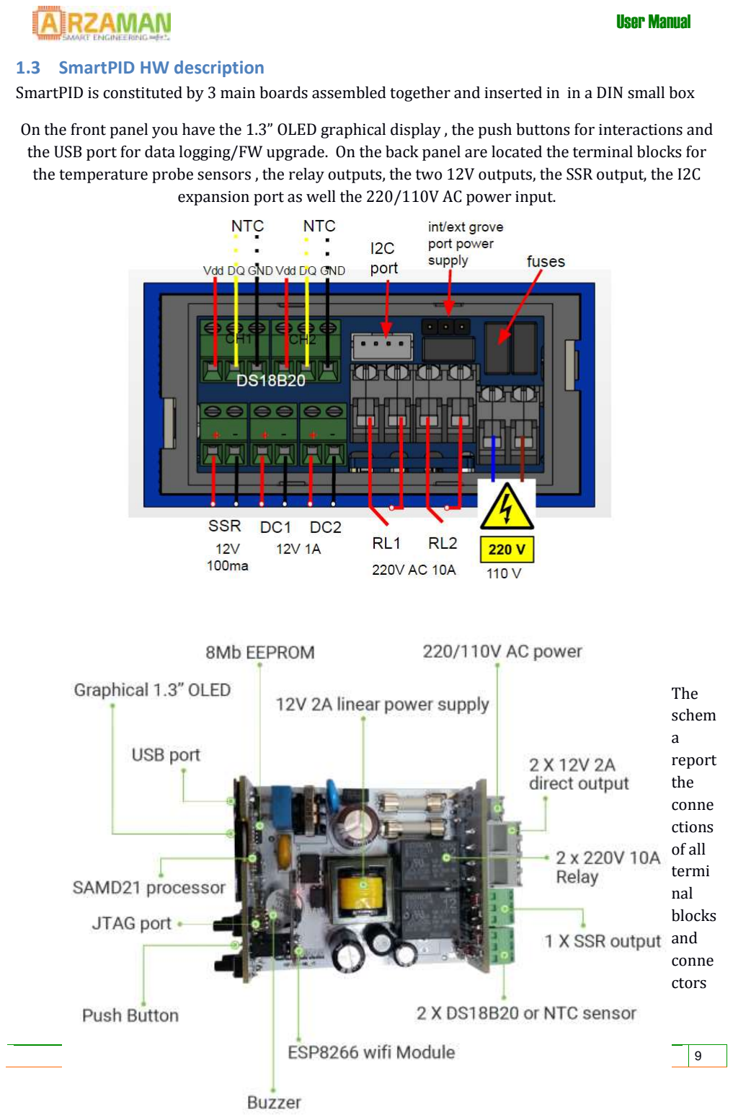
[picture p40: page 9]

### 1.3 SmartPID HW description

SmartPID is constituted by 3 main boards assembled together and inserted in in a DIN small box

On the front panel you have the 1.3” OLED graphical display , the push buttons for interactions and the USB port for data logging/FW upgrade. On the back panel are located the terminal blocks for the temperature probe sensors , the relay outputs, the two 12V outputs, the SSR output, the I2C expansion port as well the 220/110V AC power input.

The
schem
a
report
the
conne
ctions
of all
termi
nal
blocks
and
conne
ctors the 3 ports input connectors can be used either for one wire bus with DS18B20 temperature sensor (no parasitic resistor is needed) or for 10K NTC sensors.

The I2C port has a pinout compatible with grove bus with 3V3 power supply configurable (int or ext) via jumper

The Grove I2C connector has the standard layout. Pin 1 is the SCL signal and Pin 2 is the SDA signal. Power and Ground are the same as the other connectors.

pin1 | SCL | I2C Clock
pin2 | SDA | I2C Data
pin3 | VCC | Power for Grove Module, 3.3V
pin4 | GND | Ground

There are many types of I2C Grove sensors available. Most are 5V/3.3V devices, but there are a few that are only 3.3V or 5.0V. You need to check the specifications.

for further details see http://wiki.seeed.cc/Grove_System/

The front board 4 tactile switch that are used for multiple functions

a) UP/DOWN
a. Scroll in configuration menu
b. Increase decrease temperature value
c. Scroll in value in configuration menu
a) SET
d. Select/enter a specific menu
e. Select/confirm a specific value
f. Confirm action upon prompt request
b) Start/Stop
g. Start process
h. Stop Process
i. long press exit from the current menu

UP

### DOW

N

S/S

SE
T

## 2 SmartPID integration

Via HW set up configuration SmartPID can be adapted to mange different applications, the HW configuration allows to assign different processes/logicalchannels to different physical HW resources.

Below some example to illustrate the flexibility and multiple configurations possible (more details in the application manuals)

Single channel – PID (on/off) control mode – heating + pump

SmartPID reads temperature from 1 probe and drive the heating element via SSR out

Possible heating output configurations

- SSR for electric heating [PID+PWM control algorithm]
- 220V AC relay for electric heating [ON/OFF algorithm]
- Direct solenoid valve drive for GAS heating [ON/OFF algorithm]

Manually drive the PUMP (soft switch) with tow possible configurations

- 220V AC realy pump drive
- 12V DC direct pump drive

DUAL channel – PID (on/off) control mode – heating (gas or electric)

SmartPID reads temperature from 2 probe and drive 2 heating element interdependently in order to mange two different heating process

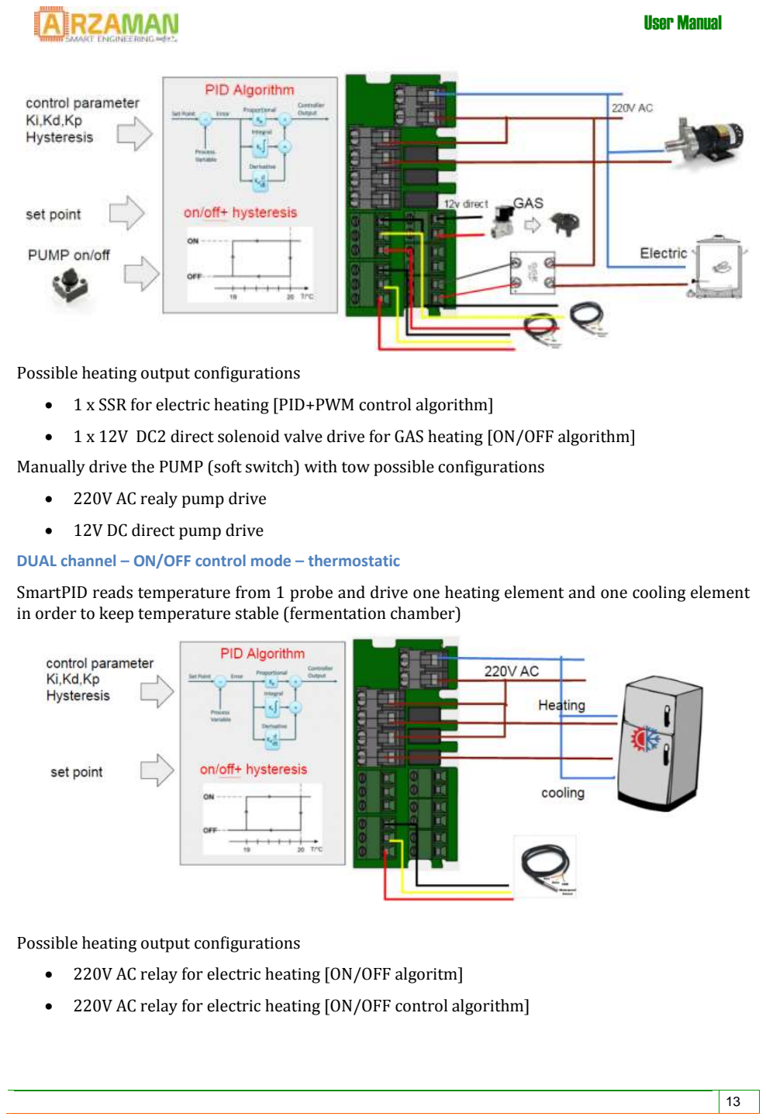
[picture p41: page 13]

Possible heating output configurations

- 1 x SSR for electric heating [PID+PWM control algorithm]
- 1 x 12V DC2 direct solenoid valve drive for GAS heating [ON/OFF algorithm]

Manually drive the PUMP (soft switch) with tow possible configurations

- 220V AC realy pump drive
- 12V DC direct pump drive

DUAL channel – ON/OFF control mode – thermostatic

SmartPID reads temperature from 1 probe and drive one heating element and one cooling element in order to keep temperature stable (fermentation chamber)

Possible heating output configurations

- 220V AC relay for electric heating [ON/OFF algoritm]
- 220V AC relay for electric heating [ON/OFF control algorithm]

## 3 SmartPID wifi configuration

SmartPID has an internal wifi module that allow the application to communicate to an external server and push all log data and process parameters. The wifi module implement also a web server and via a smartphone dedicated app or a browser it's possible to :

1. perform the initial setup and configure once the relevant parameters
2. retrieve and visualize the log data from the cloud server
3. Modify from remote the set point [in run mode]

the SmartPID architecture for data logging is client-server and in order to manage and store data in

the cloud public thingspeak service is used

For more details on powerful thingspeak features refer to https://thingspeak.com

Each smartPID is associated to a thingspeak channel that is uniquely identified by a channel ID. Each thingspeak account can have multiple channels and so you can manage multiple smartPID from one thingspeak account. The channel is the logical entity that contains process data generated by smartPID and has a set of predefined field corresponding to process data

In order to complete the wifi configuration and thingspeak logical channel associations 4 mains logical step must be executed

1. Create a thingspeak account and create the channel with proper structure
2. Create a smartPID account using the smartphone app and associate to the thinsgspeak account. A unique “user API KEY” is used to adress the proper thingspeak channel
3. Activate WiFi on smartPID and connect the smartphone (or laptop) with direct connection
4. Configure the smartPID via smartphone app (or web browser) updating following values
a) Wifi SSID and password
b) Channel ID to associate to the smartPID
c) web server port / baud rate [can be left to default value]

### 3.1 Thingspeak server configuration

This operation is done on thingspeak server and is independent from smartPID configuration

1. Connect to https://thingspeak.com/
2. Select Sign Up:

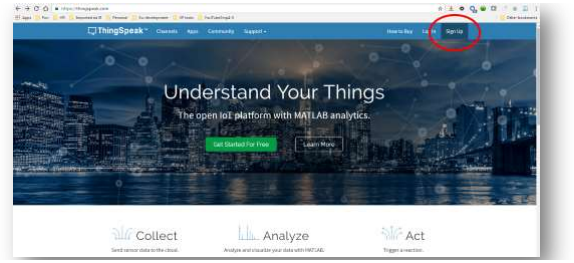
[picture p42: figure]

3. Select Create account and fill the form

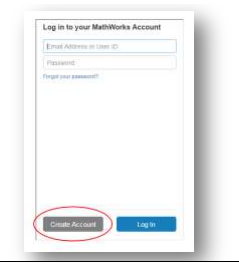
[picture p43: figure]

4. Verify Your account: go to your inbox and click the link in the received email
5. Press Continue and Sign in with your credentials and agree to terms.

Now you need to create a channel to feed the data from SmartPID, each channel can be public or private depending on your needs

6. Press on New Channel:
7. Fill the form for channel definition

Note that Name and Description can be filled as you prefer, the other fields must be filled as suggested , same order and labels

All the other fields can be left empty.

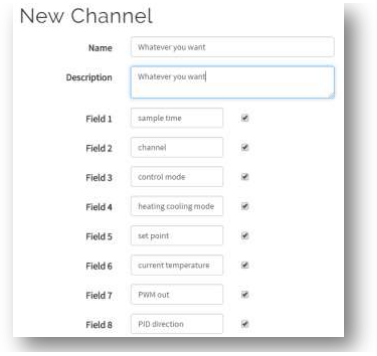
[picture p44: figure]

8. Press Save Channel and take note of your channel ID that should be uniquely assigned to your smartPID
9. Select ACCOUNT→ my profile and take note of the USER API KEY

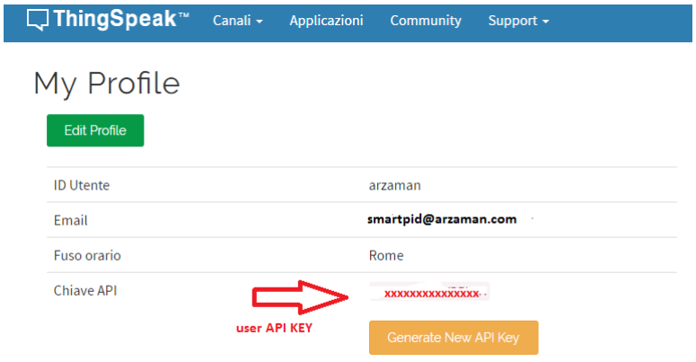
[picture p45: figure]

The user API key is the way smartPID connects to your channel in a secure and trusted way and you have to insert it in the SmartPID configuration phase via the smartphone app.

### 3.2 WiFi Configuration

In this paragraph it is explained how to configure the SmartPID WiFi connection provided the internal ESP8266 WiFi module

In order to input in an easy way all the relevant data (SSID, WIFI PWD , user API KEY etc…) you can use your smartphone and a dedicated app [android 5.0 or greater] that connects directly to the SmartPID or in alternative a laptop PC using any browser

SmartPID configuration
The wifi module can be configured in various mode 0=off, 1= Client Mode , 2= AP mode, 3= Auto this mode will be used for the parameter configuration over WiFi
1. Take your smartPID device and take familiarity with the interface:

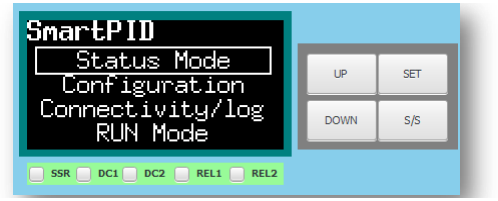
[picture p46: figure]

2. Select Connectivity/log on the smartPID device and press SET (upper right button):
3. Select Wi-Fi and press the SET button:

4. Set Wi-Fi mode to Auto and press the SET button
in this configuration the wifi module broadcast a wifi signal SPC1000_xxxxxxx where xxxxxxx is your device serial number

Smartphone APP configuration

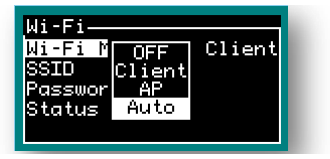
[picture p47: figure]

5. Go to the Play Store and install SmartPID app on your Android smartphone
6. Launch the app and sign up in order to link the app with the thingspeak (https://play.google.com/store/apps/details?id=fred.com.smartpid) profile

You should register your SmartPID account using a valid email address , your password and insert the USER API KEY that you note down from your thingspeak profile [see chapter 3.2 ,
step 9]

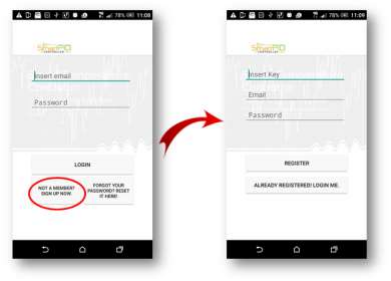
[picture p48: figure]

7. Choose in the App SETUP-> Wi-Fi setup

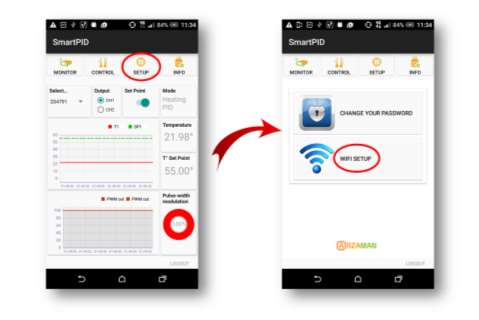
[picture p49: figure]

8. The app scans all available WiFi netwoks , keep you smartphone close to SmartPID. Choose SPC1000_xxxxxxxx network (xxxxxxxx is the serial number of your smartPID) and insert the following default password: smartpid! and press the Next button:

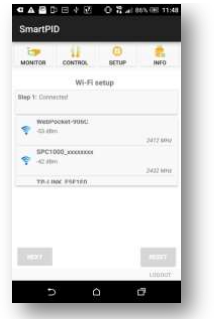
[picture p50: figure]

9. Choose your home Wi-Fi network, insert the password of your router and all the other parameters if necessary like the channel ID that you want to associate to your smartPID, the port and the baud rate and press the Next button

SmartPID connection to WiFi router

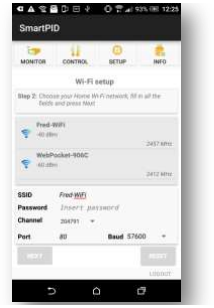
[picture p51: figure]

Once you have configured the smartPID it will reboot automatically and immediately after it try to connect to your WiFi router. If all the values are correct you should see the smartPID connected to your home WiFi router. In order to verify the proper configuration on smartPID follow below steps

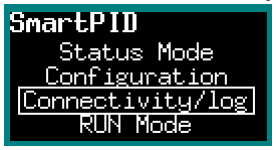
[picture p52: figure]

10. Select Connectivity/log on the smartPID device from the top menu and press the SET button
11. Select Logging and set it to Wi-Fi and press the SET button

12. Select status menu and your IP address assigned by the router and your SSID wil be reported. IP address is useful if you want to control your smartPID from remote via app

Process parameter logging

Now you can activate your logging via wifi and verify the thingspeak server connection

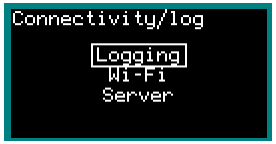
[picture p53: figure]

13. Got to the connectivity and log menu and select logging
14. activate the log via WiFi
15. Select the status and press the SET button

Now every time that SmartPID is in RUN MODE the process data for each channel (set point, current temperature and PWM percentage) are pushed to the things peak server.

You can visualize your data either on your channel on thingspeak account or on the smartphone app

For details on channel visualization or data manipulation/analysis/export on thingspeak server please refer to the thingspeak web site

https://thingspeak.com/

In the top right corner of the run mode screen you can see both indication of WiFi connection and logging activation

### 3.3 WiFi configuration via browser

In case it's not possible to use an android (5 or greater) smartphone it's possible to complete the Wi-Fi configuration using a web browser on a laptop of even on the smartphone browser

The thingspeak configuration steps and smartPID steps are exactly the same, what changes is that instead using the app to input the parameter a web form inside a browser can be used

connect to the SPC1000_xxxxxxxxxxx wifi network using your wifi connection manger and open the browser at the following url

http://192.168.4.1

the browser will present a form to be filled

the value that are needed are

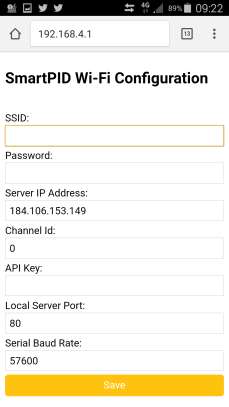
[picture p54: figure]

1. SSID of the Wi-Fi network to connected
2. PWD of the wifi network
3. Server IP address is the thingspeak server 184.106.153.149

4. Channel ID is the value associated to the channel during the thingspeak setup
5. API KEY is the user API KEY
6. Serial baud rate is the communication speed between Wi-Fi module and the controller

once you have saved the value the smartPID reboot and the next steps are same as for the configuration via smartphone

## 4 Arduino configuration

SmartPID platform is 100% compatible with the arduino ecosystem since SmartPID processor is the SAMD21G (arm cortex M0+) used in arduino zero and MKR1000 platform.

In order to program your SmartPID using the Arduino IDE it's necessary to install some components and drivers.

### 4.1 Windows USB driver installation – virtual com

In order to install the USB driver and create a virtual seril com you need to follow below steps

After plugging the board in, Windows will try – and fail – to search the Internet for drivers. Click the button below link to download the driver.

DOWNLOAD THE SAMD21 WINDOWS DRIVERS (https://github.com/arzaman/smartPID/tree/master/Driver/SmartPID-SPC1000-USB-DRIVER)

1.After downloading copy down the location of the araman.inf files.

2.Open your Device Manager

•In Windows 8 or 10, simply search for "Device Manager" and select the Windows app
•See Window's resources for Windows 7. (http://windows.microsoft.com/en-us/windows/open-device-manager#1TC=windows-7)
•(Start > Run > "devmgmt.msc", should work on almost any version of the OS.)
3.In the Device Manager, expand the"Other devices" tree-- you should see an entry for

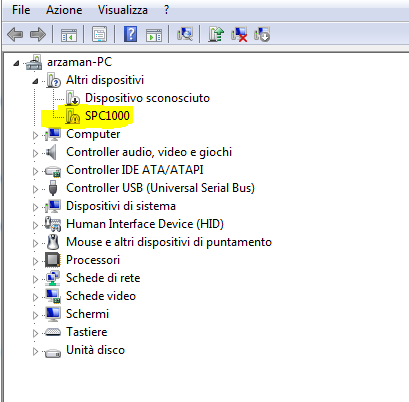
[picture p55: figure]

Screenshot: Navigating the Device Manager (https://learn.sparkfun.com/tutorials/samd21-minidev-breakout-hookup-guide/hardware-setup#collapseOne)

4."Unknown Device",Right-click on SPC1000 and select Update Driver Software...

5.Select Browse my computer for driver software. On the next screen

Screenshot: Browse your computer for the driver (https://learn.sparkfun.com/tutorials/samd21-minidev-breakout-hookup-guide/hardware-setup)

6.Paste the directory location of your arzaman.inf and files into the search location. Then hit "Next".


Screenshot: Setting the driver location (https://learn.sparkfun.com/tutorials/samd21-minidev-breakout-hookup-guide/hardware-setup)

7.Click "Install"when the next pop-up questions if you want to install the driver.

8. If you get any security warning please proceed with installation


Screenshot: (https://learn.sparkfun.com/tutorials/samd21-minidev-breakout-hookup-guide/hardware-setup) security warning

9.The driver installation may take a moment, when it's done you should be greeted with a "successfully updated your driver software" message!


10.Once the installation is completed you should see the serial com created

### 4.2 MAC and Liux USB driver

Mac and Linux users shouldn’t need to download any drivers. The device should show up as a serial port as soon as it’s plugged in to your computer.

### 4.3 Setting up Arduino IDE

SAMD21 MCU is fully supordet by Arduino IDE you just need to add ARM Cortex-M0+-support to your Arduino IDE. This page will list every step required for getting SmartPID SAMD21 controller support into your Arduino IDE.

Update Arduino! This setup requires at least Arduino version 1.6.4 or later. We've tested it on IDE 1.6.13 . If you're running an older version of Arduino, consider visiting arduino.cc to get the latest, greatest release.

First, you’ll need to install a variety of tools, including low-level ARM Cortex libraries full of generic code, arm-gcc to compile your code, and bossa to upload over the bootloader. These tools come packaged along with Arduino’s SAMD board definitions for the Arduino Zero.

To install the Arduino SAMD board definitions, navigate to your board manager (Tools > Board > Boards Manager…), then find an entry for Arduino SAMD Boards (32-bits ARM Cortex-M0+). Select it, and install the latest version (recently updated to 1.6.13)


Downloading and installing the tools may take a couple minutes – arm-gcc in particular will take the longest, it’s about 250MB unpacked.

Once installed, Arduino-blue “Installed” text should appear next to the SAMD boards list entry.

Now that your ARM tools are installed, one last bit of setup is required to add support for the SmartPID board definition. First, open your Arduino preferences (File > Preferences). Then find the Additional Board Manager URLs text box, and paste the below link in:

https://raw.githubusercontent.com/arzaman/smartPID/master/Driver/SPC1000/package_arzaman_index.json

Then hit “OK”, and travel back to the Board Manager menu. You should (but probably won’t) be able to find a new entry for Arzaman SAMD Boards. If you don’t see it, close the board manager and open it again.


Once you have installed the SmartPID – SPC100 bord defintion you should see two one entries in your Tools > Board list: Select your SmartPID - SPC1000 Board.


## 5 Compiling and uploading sketch

Once you have install the SAMD core components and the SmartPID – SPC1000 board definition you are ready to develop and compile your sketch as any ordinary arduino code.

In order to support some basic functions you need to install locally the library that are available on github

https://github.com/arzaman/smartPID/tree/master/Libraries

To upload the binary file a special boot-loader has been developed based on Mass Storage device (MSD) technology. The bootloader replace the SAM-BA original atmel bootloader

The binary file is NOT loaded via the serial interface uing BOSSA tool insuide the IDE but is simply copy pasted in the smartPID board that is mapped as a USB memory drive [see chapter FW upgrade]

Once you have complied successfully the sketch you can export the binary file in your sketch folder


Than simply copy-paste the <sketch name>.bin file in the USB memory drive and than safely remove the drive and reboot the controller

## 6 Firmware upgrade

The firmware upgrade can be performed very easily using the MSD mass storage device bootloader technology that allow you to “copy paste” the binary executable file in the smartPID controller connected via USB and mapped as a USB memory

To upgrade FW you DON’T need any driver or SW installation, just simply follow below steps

Programming an application via the bootloader

1. power up the board while keeping the S/S button pressed: the OLED display will be lit with a solid white color
2. connect the board to a USB port, it will appear as a mass storage device and the OLED display will alternate between a black and a white screen
3. remove the FLASH.BIN file present in the mass storage device
4. copy the your executable .bin file of your application to the mass storage device
5. safely remove the USB mass storage device from the PC
6. power-cycle the board and reboot

## 7 Factory reset

If you need restoring application settings to factory default settings (internal EEPROM erase) you perform via the bootloader following operation

power up the board while keeping the DOWN button pressed: the OLED display will report the "Init EEPROM" message indicating that application settings have been reset to factory defaults; after a few seconds, the application will start with default settings

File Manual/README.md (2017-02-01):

# manual

this folder contains the SmartPID manuals

Quick start guide
very short introduction and basic operation

Installation and configuration manual
provide all instruction to:
install and connect smartPID to your ecosystem,
hw configuration,
wifi setup and data logging via thingspeak service,
Arduino IDE connection and programming,
FW upgrade and reset to factory

Application manual
provide instruction for the application usage and configuration:
Smart home-brewing app and Smart thermostat

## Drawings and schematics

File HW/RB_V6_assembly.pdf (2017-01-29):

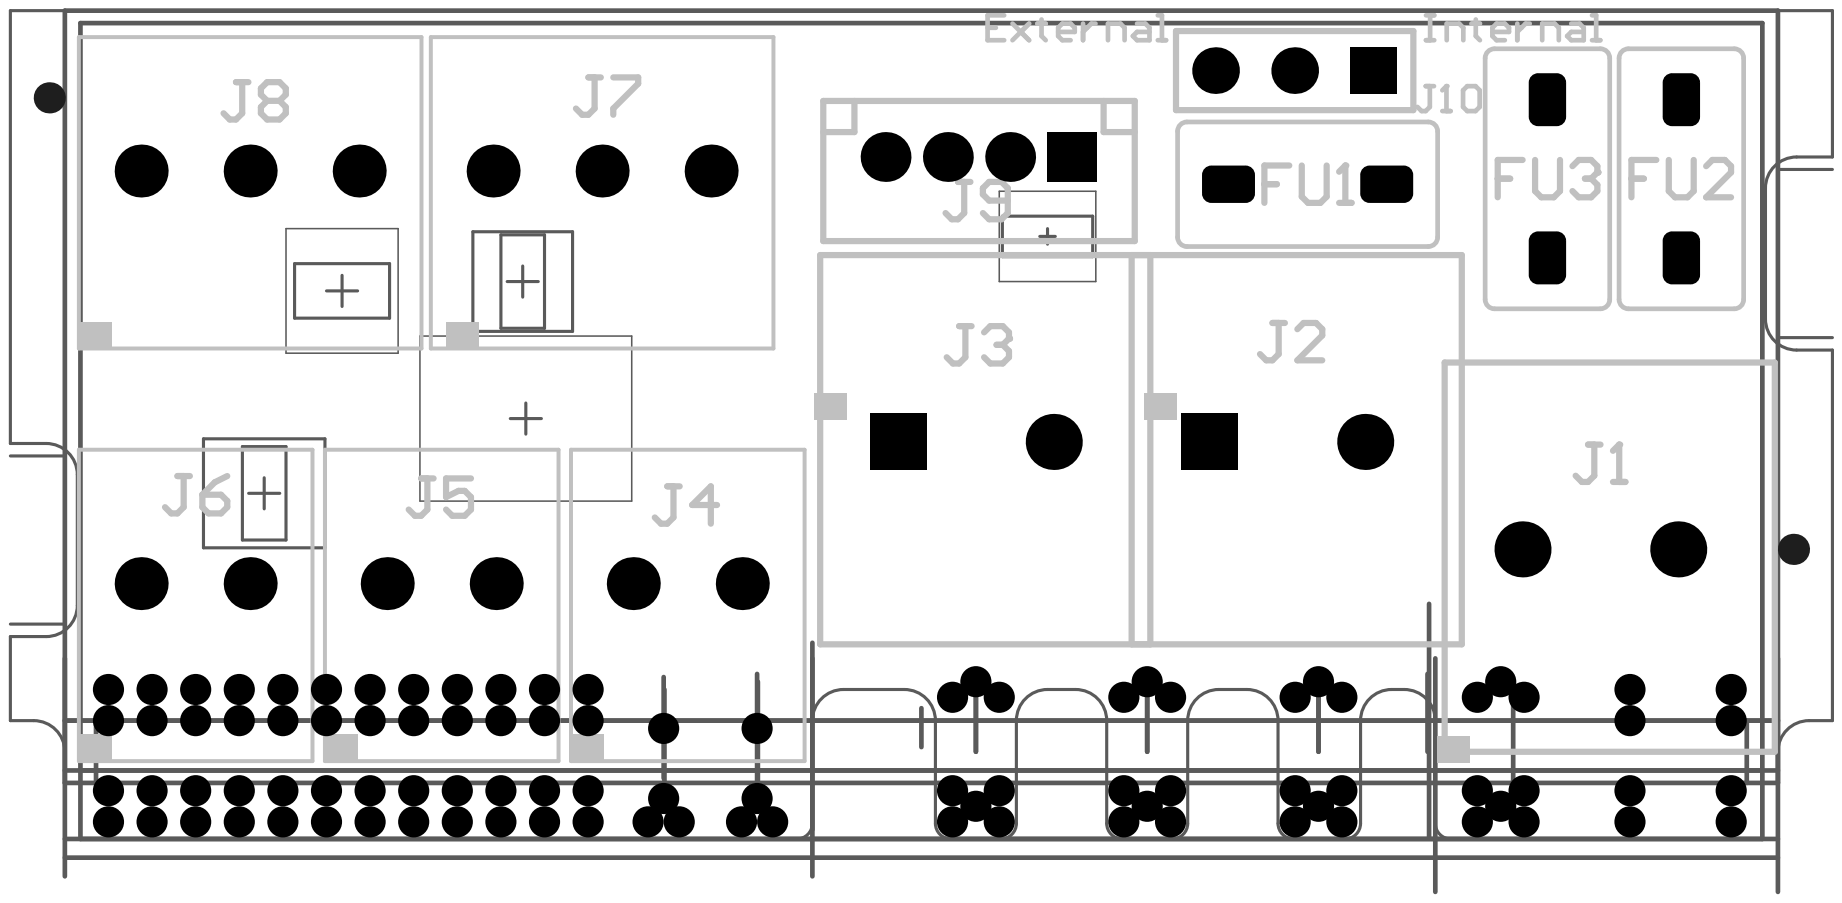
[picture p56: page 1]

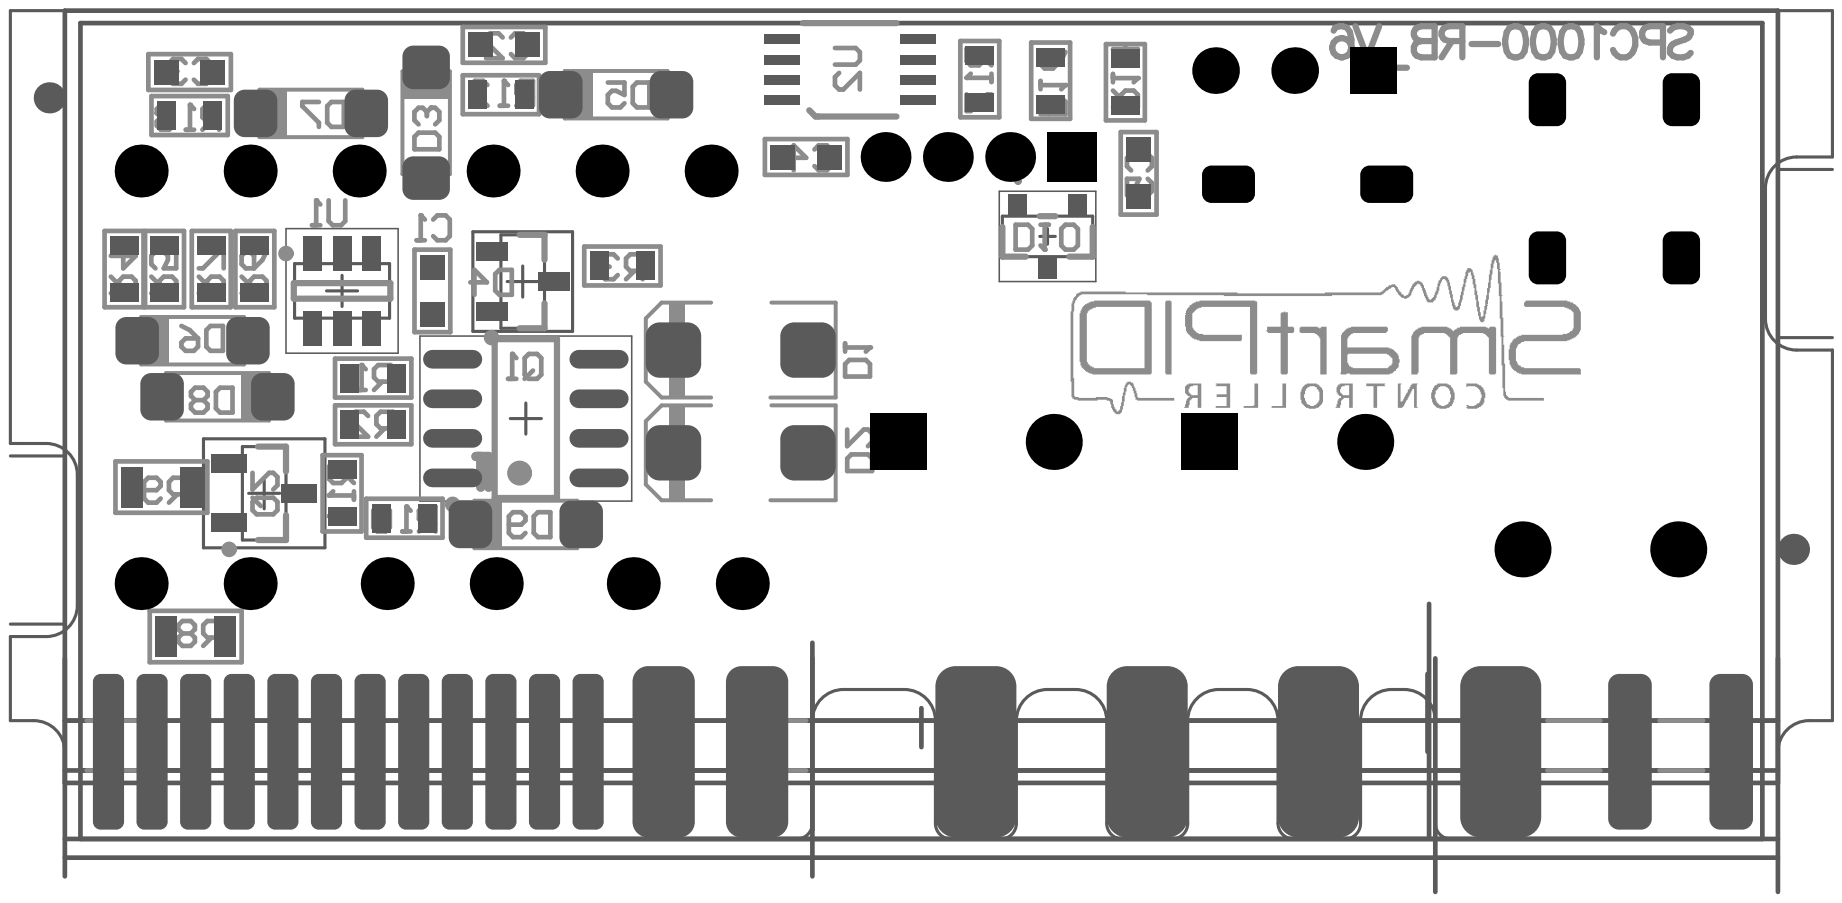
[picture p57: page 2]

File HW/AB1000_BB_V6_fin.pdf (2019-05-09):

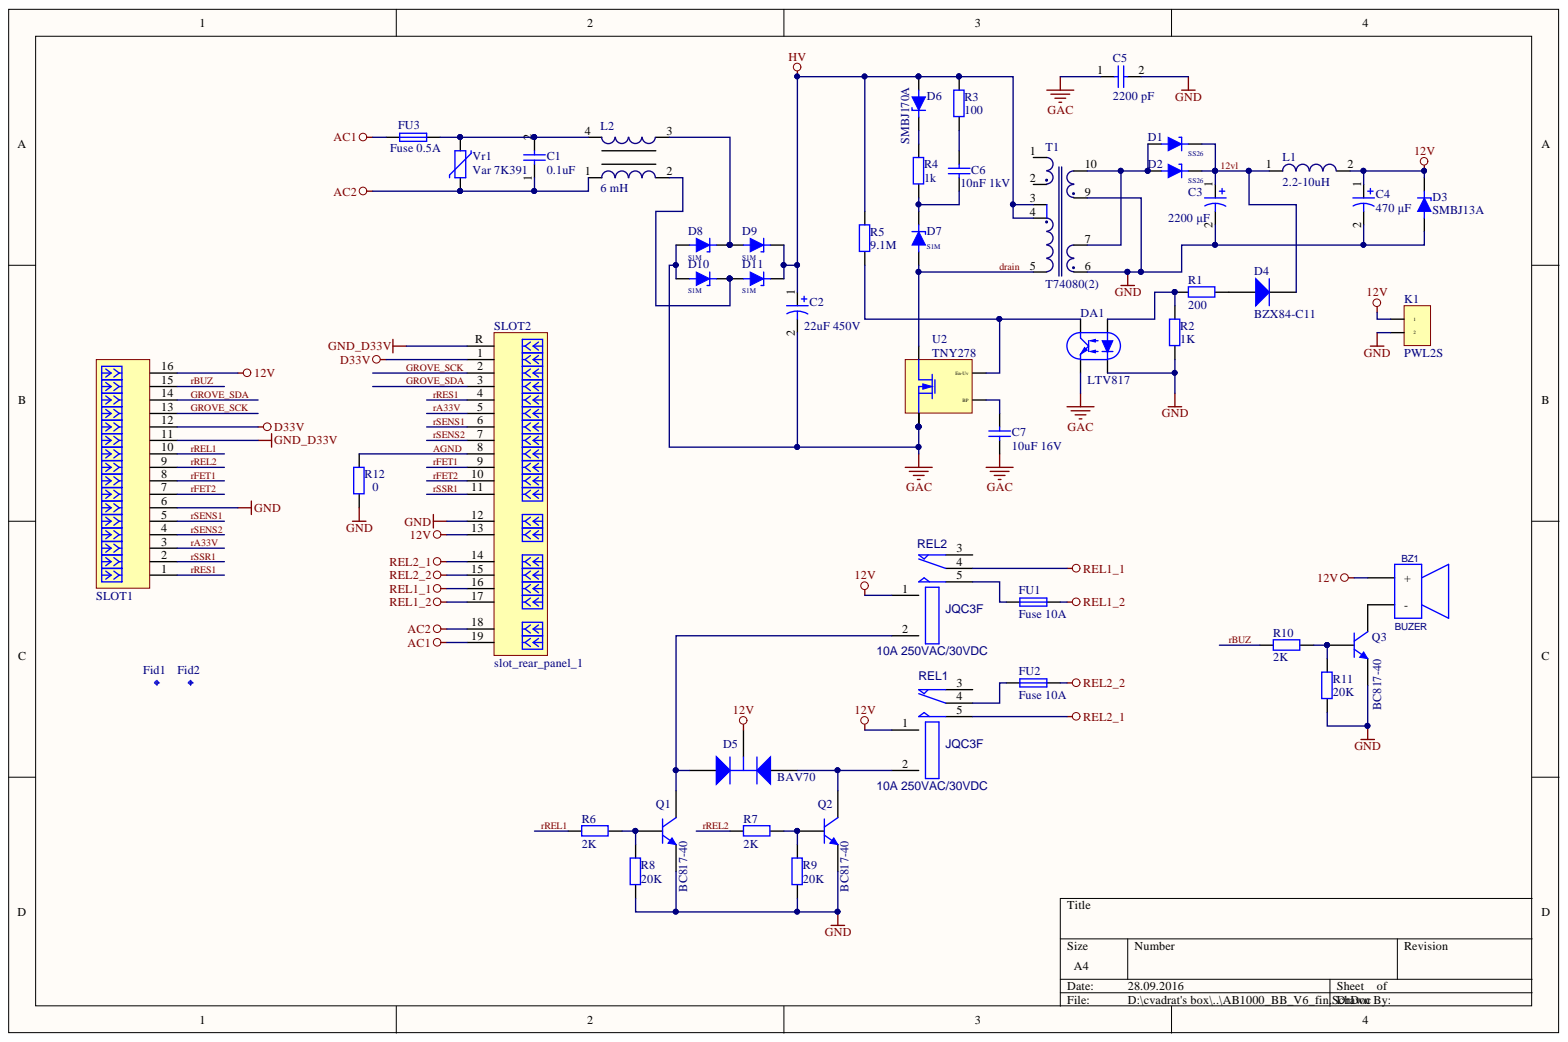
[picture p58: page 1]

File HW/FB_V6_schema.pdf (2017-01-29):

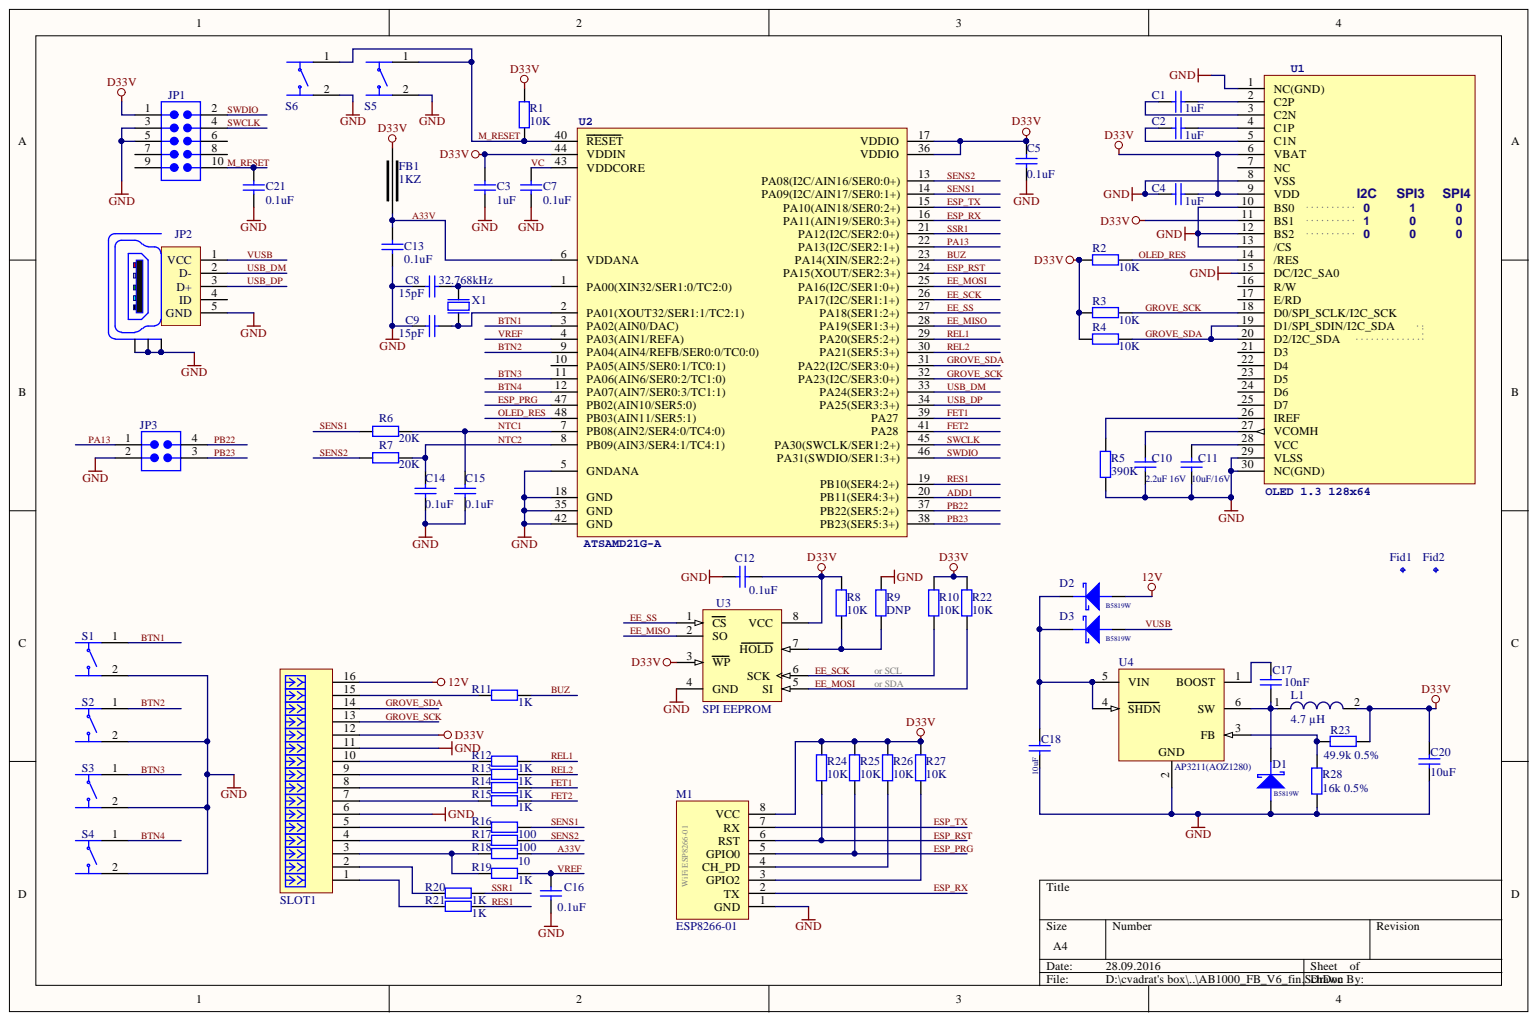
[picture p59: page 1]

SHDN 4

9 R13 | 1K REL2
8 R14 | 1K FET1

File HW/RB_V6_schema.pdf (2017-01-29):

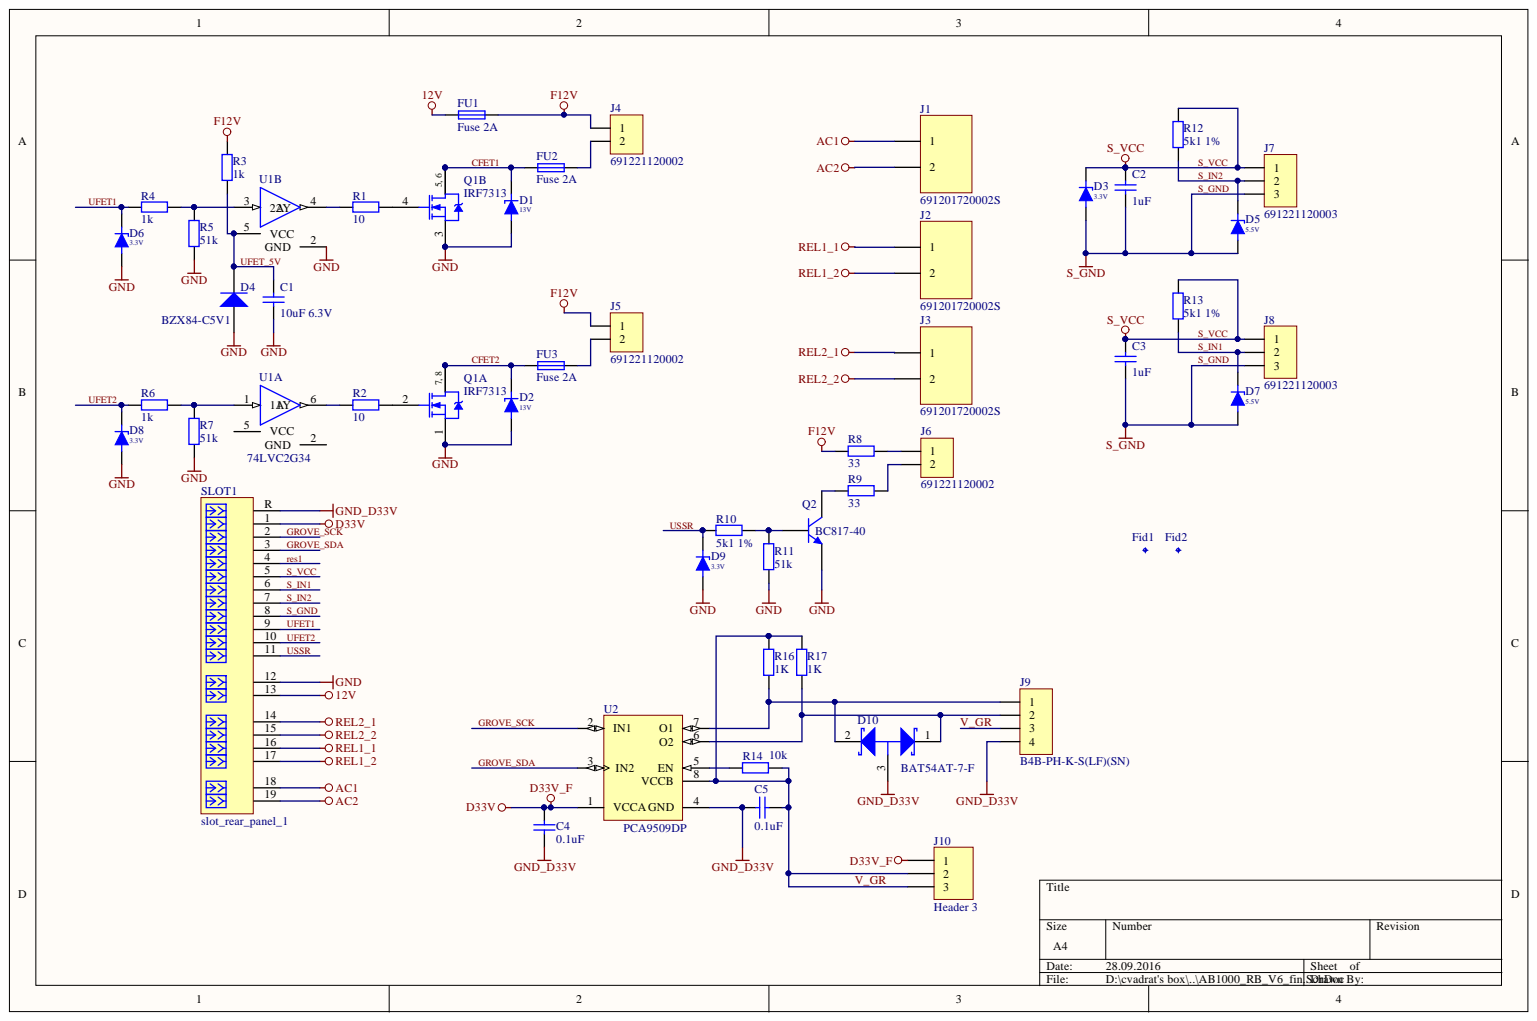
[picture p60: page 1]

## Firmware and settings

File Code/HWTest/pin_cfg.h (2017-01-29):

#ifndef __PIN_CFG_H
#define __PIN_CFG_H

//#define DSwire1 A,9,IN
//#define DSwire2 A,8,IN
#define DSwire1 PORT_A,9
#define DSwire2 PORT_A,8

#define NTC_probe1 PORT_B,8
#define NTC_probe2 PORT_B,9
#define ADC_REF PORT_A,3


//#define DSwire1_pin PORT_A,9


#endif

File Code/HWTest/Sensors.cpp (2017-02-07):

#include "ABM_Cfg.h"
#include "Sensors.h"
#include "storage_var.h"
#include "vsd_macros.h"
#include "pin_cfg.h"
#include "delay.h"
#include <system_interrupt.h>
#include <math.h>

const int timing_ds[] = {6, 64, 60, 10, 9, 55, 0, 480, 70, 410};
//const int overdriveT[] = {1.5, 7.5, 7.5, 2.5, 0.75, 7, 2.5, 70, 8.5, 40};

uint32_t NTC1_ADC_val, NTC2_ADC_val;

//uint8_t sensor1_mode=SENSOR_ONEWIRE, 
//uint8_t sensor2_mode=SENSOR_NTC;
uint16_t sensor1_count, sensor2_count;
uint8_t temp_sens1[9],temp_sens2[9];
float sensor1_fval,sensor2_fval;

#define wait_us(x) delayMicroseconds(x)

//******************************************************************************
void sync_ADC() {
  while (ADC->STATUS.bit.SYNCBUSY == 1) ;
}
//******************************************************************************
void writePin(PortGroup *port, uint8_t pin, uint8_t val)
{
if(val) port->OUTSET.reg = (uint32_t)(1<< pin);
else port->OUTCLR.reg = (uint32_t)(1<< pin);
}
//******************************************************************************
void ADC_CannelSet(uint8_t chn)
{
sync_ADC();
ADC->INPUTCTRL.bit.MUXPOS = chn;
}
//******************************************************************************
void ADC_Enable(void)
{
sync_ADC();
ADC->CTRLA.bit.ENABLE = 0x01;             // Enable ADC
}
//******************************************************************************
void ADC_FakeConversion(void)
{
  sync_ADC();
  ADC->CTRLA.bit.ENABLE = 0x01;             // Enable ADC

  // Start conversion
  sync_ADC();
  ADC->SWTRIG.bit.START = 1;

  // Clear the Data Ready flag
  ADC->INTFLAG.bit.RESRDY = 1;
}
//******************************************************************************
void ADC_StartConversion(void)
{
  // Start conversion
  sync_ADC();
  ADC->SWTRIG.bit.START = 1;
}
//******************************************************************************
uint32_t ADC_ValueRead(void)
{
uint32_t ret_val;
  while ( ADC->INTFLAG.bit.RESRDY == 0 );   // Waiting for conversion to complete
  ret_val = ADC->RESULT.reg;
return ret_val;
}
//******************************************************************************
void ADC_Disable(void)
{
  sync_ADC();
  ADC->CTRLA.bit.ENABLE = 0x00;             // Disable ADC
  sync_ADC();
}
//******************************************************************************
void ADC_SetReference(void)
{
ADC->INPUTCTRL.bit.GAIN = ADC_INPUTCTRL_GAIN_1X_Val;      // Gain Factor Selection
ADC->REFCTRL.bit.REFSEL = ADC_REFCTRL_REFSEL_AREFA_Val;
}
//******************************************************************************
void SensorsSetup(void)
{
InitPin(NTC_probe1,INA);
InitPin(NTC_probe2,INA);
InitPin(ADC_REF,INA);
ADC_SetReference();
ADC_Enable();
}
//******************************************************************************
uint8_t onewire_readBit(void) 
{
    uint8_t result=0;
    
system_interrupt_enter_critical_section();
    if(_stv.HW_var.probe1_mode==SENSOR_ONEWIRE) InitPin(DSwire1,OUTL);
    if(_stv.HW_var.probe2_mode==SENSOR_ONEWIRE) InitPin(DSwire2,OUTL);

    wait_us(6/*6*//*timing[0]*/);
    if(_stv.HW_var.probe1_mode==SENSOR_ONEWIRE) InitPin(DSwire1,IN);
    if(_stv.HW_var.probe2_mode==SENSOR_ONEWIRE) InitPin(DSwire2,IN);
    wait_us(9/*9*//*timing[4]*/);
    if(_stv.HW_var.probe1_mode==SENSOR_ONEWIRE) result|=ReadPin(DSwire1);
    if(_stv.HW_var.probe2_mode==SENSOR_ONEWIRE) result|=ReadPin(DSwire2)<<1;
system_interrupt_leave_critical_section();
       
    return result;
}
//******************************************************************************
void onewire_writeBit(uint8_t bit1,uint8_t bit2)
{
    bit1 = bit1 & 0x01;
    bit2 = bit2 & 0x01;
uint8_t n=0,b=0;
    
system_interrupt_enter_critical_section();
if(_stv.HW_var.probe1_mode==SENSOR_ONEWIRE) {InitPin(DSwire1,OUTL); n++;}
if(_stv.HW_var.probe2_mode==SENSOR_ONEWIRE) {InitPin(DSwire2,OUTL); n++;}
wait_us(6/*6*//*timing[0]*/);
if((bit1!=0) && (_stv.HW_var.probe1_mode==SENSOR_ONEWIRE)) {InitPin(DSwire1,IN); b++;}
if((bit2!=0) && (_stv.HW_var.probe2_mode==SENSOR_ONEWIRE)) {InitPin(DSwire2,IN); b++;}
if(n==b) {
system_interrupt_leave_critical_section();
return;
}
wait_us(60-3/*timing[2]*/);
if(/*(bit1==0) && */(_stv.HW_var.probe1_mode==SENSOR_ONEWIRE)) {InitPin(DSwire1,IN);}
if(/*(bit2==0) && */(_stv.HW_var.probe2_mode==SENSOR_ONEWIRE)) {InitPin(DSwire2,IN);}

#if 0
if (bit)
    {
//        InitPin(DSwire1,OUTL);
        wait_us(3/*6*//*timing[0]*/);
        InitPin(DSwire1,IN);
    }
    else
    {
//        InitPin(DSwire1,OUTL);
        wait_us(60/*timing[2]*/);
        InitPin(DSwire1,IN);
    }
#endif
system_interrupt_leave_critical_section();
}
//******************************************************************************
void read_onewire_bit(uint8_t *data1, uint8_t *data2, uint8_t bit)
{
uint8_t bit_res=onewire_readBit();
  (*data1)=((*data1)&~(1<<bit)) | ((bit_res & 0x01)<<bit);
  (*data2)=((*data2)&~(1<<bit)) | (((bit_res>>1) & 0x01)<<bit);
}
//******************************************************************************
void write_onewire_bit(uint8_t data, uint8_t bit)
{
onewire_writeBit(data>>bit,data>>bit);
}
//******************************************************************************
float NTC_to_Temp(uint32_t in)
{
float tconv;
tconv=in;
// Convert value to resistance
tconv = 1023 / tconv - 1;
tconv = NTC_PULL_RESISTOR / tconv;

//Calculate temperature using the Beta Factor equation
float temperatura;
temperatura = tconv / NTC_RESISTANCE;     // (R/Ro)
temperatura = log(temperatura); // ln(R/Ro)
temperatura /= BCOEFFICIENT;                   // 1/B * ln(R/Ro)
temperatura += 1.0 / (TEMPERATURENOMINAL + 273.15); // + (1/To)
temperatura = 1.0 / temperatura;                 // Invert the value
temperatura -= 273.15;                         // Convert it to Celsius
if (_stv.UnitPar.temper_unit == T_CELSIUS)
	return temperatura;
else
	return CELSIUS_TO_FAHRENHEIT(temperatura);
}

/* Convert a raw value read from DS18B20 to a temperature value
 * Parameters:
 * - in: raw 16-bit value read from DS18B20
 * Returns: temperature value, in either Celsius or Fahrenheit depending on the
 * current user setting
 */
float DS18B20_Temp(uint16_t in)
{
  float val;

  val = in >> 4;
  val += (double)(in & 0x0f) * 0.0625;
  if (_stv.UnitPar.temper_unit == T_CELSIUS)
    return val;
  else
    return CELSIUS_TO_FAHRENHEIT(val);
}
//******************************************************************************
void MathSensorsValues(void)
{
  uint16_t tsens;
  if(_stv.HW_var.probe1_mode==SENSOR_ONEWIRE) {
  sensor1_fval = DS18B20_Temp(*((uint16_t*)temp_sens1));
  }
  if(_stv.HW_var.probe2_mode==SENSOR_ONEWIRE) {
  sensor2_fval = DS18B20_Temp(*((uint16_t*)temp_sens2));
  }
  if(_stv.HW_var.probe1_mode==SENSOR_NTC) {
  sensor1_fval=NTC_to_Temp(NTC1_ADC_val);
  }
  if(_stv.HW_var.probe2_mode==SENSOR_NTC) {
  sensor2_fval=NTC_to_Temp(NTC2_ADC_val);
  }
}
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
